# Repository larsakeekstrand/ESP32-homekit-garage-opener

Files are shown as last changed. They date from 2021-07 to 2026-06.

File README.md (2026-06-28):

# ESP32 Homekit garage door opener
## Introduction
This is a homekit garage opener for the ESP32. It's a bit a work in progress, but it should mostly work.

Features:
* Controls a relay that opens/closes the door.
* Uses a reed sensor to detect if the door is open/closed.
* Contains a DHT22 temperature/humidity sensor.

Schematics for the hardware can be found [here](https://github.com/larsakeekstrand/ESP32-homekit-garage-opener/blob/478886ba8ccb8f31c0db583b10b282738d822965/docs/Schematic_GarageOpener.pdf). The schematics is made using [EasyEDA](https://easyeda.com/)

STL files for the housing can be found [here](https://github.com/larsakeekstrand/ESP32-homekit-garage-opener/blob/2dc0cb2f88ffee0f719a3f48c10d991301077dc2/docs/GarageOpenerTop.stl), [here](https://github.com/larsakeekstrand/ESP32-homekit-garage-opener/blob/2dc0cb2f88ffee0f719a3f48c10d991301077dc2/docs/GarageOpenerBottom.stl) and [here](https://github.com/larsakeekstrand/ESP32-homekit-garage-opener/blob/d89407ebe4e6d4afd1c8a517a600cc80013ba3aa/docs/GarageOpenerBottomButton.stl).

An overview of how to assemble the housing can be found [here](https://github.com/larsakeekstrand/ESP32-homekit-garage-opener/blob/d89407ebe4e6d4afd1c8a517a600cc80013ba3aa/docs/GarageOpenerCompleteNotPrintable.stl).

## Getting started
### Setup host environment

Set up the host environment and **Espressif ESP-IDF v5.5.2** using the instructions given [here](https://docs.espressif.com/projects/esp-idf/en/latest/get-started/index.html).

Set up the Espressif esp-homekit-sdk using the instructions given [here](https://github.com/espressif/esp-homekit-sdk).

The DHT22/AM2301 driver is fetched automatically by the **ESP Component Manager** (declared in `main/idf_component.yml`) — no separate clone of `esp-idf-lib` is required.

### Get ESP32-homekit-garage-opener

Clone this repository **alongside** (not inside) your `~/esp/` directory:

```
cd ~/source    # ~/source is a sibling of ~/esp
git clone https://github.com/larsakeekstrand/ESP32-homekit-garage-opener
```

After the installation the directory structure should look like this:

```
~/
  esp/
    esp-idf            # ESP-IDF v5.5.2
    esp-homekit-sdk    # Espressif HomeKit SDK (cloned peer)
  source/
    ESP32-homekit-garage-opener   # this repo
```

`CMakeLists.txt` locates `esp-homekit-sdk` at `../../esp/esp-homekit-sdk` relative to the repo root, or via the `HOMEKIT_PATH` environment variable.

### Configure
Source the ESP-IDF environment, then run `idf.py menuconfig` to set Wi-Fi credentials and the HomeKit setup code before flashing:
```bash
. ~/esp/esp-idf/export.sh
cd ~/source/ESP32-homekit-garage-opener
idf.py menuconfig
```

Set the Wi-Fi SSID and password under **App Wi-Fi configuration**. Set the HomeKit setup code and ID under **HAP Setup** (or leave the hardcoded defaults for development).

### Compile and Flash

```bash
idf.py set-target esp32
idf.py build
idf.py flash monitor
```

## Continuous Integration & Releases



### CI (automatic)

Every push to `main` and every pull request targeting `main` triggers the **Build** workflow
(`.github/workflows/build.yml`). It:

- Builds the firmware with ESP-IDF v5.5.2 and target `esp32`.
- Verifies the image fits the 1600 KB OTA partition.
- Uploads `garage.bin` as a downloadable artifact.

Warnings in the app sources are treated as errors (`-Werror`), so a warning will fail the build.

### Cutting a release (manual)

1. Go to the **Actions** tab in GitHub.
2. Select the **Release** workflow.
3. Click **Run workflow**, enter a version string (e.g. `1.1.0`, no leading `v`), and confirm.

The workflow builds with that version baked in as `FW_VERSION`, tags the commit `v1.1.0`, and
publishes a GitHub Release with two assets: `garage.bin` and `version.txt`.

### Self-updating OTA

The device checks `releases/latest` on GitHub **every hour** (default). If `version.txt` reports a
version newer than the running firmware, the device downloads `garage.bin` via HTTPS and reboots
into the new image. A bad image that never completes initialization is **automatically rolled back**
by the bootloader.

The poll interval and repo base URL are configurable via `idf.py menuconfig` →
**Example Configuration** → OTA options (`CONFIG_OTA_POLL_INTERVAL_SEC`,
`CONFIG_OTA_GITHUB_BASE_URL`).

> **Security note:** anyone who can publish a GitHub Release to this repo can push firmware to the
> device. Images are not cryptographically signed — acceptable for a personal repo.

### Wi-Fi credentials & OTA

Wi-Fi credentials are stored in the **`nvs` flash partition**, which OTA never touches (OTA only
rewrites the inactive app slot). So **credentials persist across updates** — you don't re-enter them
when the device self-updates.

The release images built by CI are **provisioning-mode** (no credentials baked in). Don't put your
SSID/password into the build or into GitHub — provision the device instead:

- **First-time / after a reset:** when the device is unprovisioned it advertises a BLE service named
  `PROV_XXYYZZ` (last 3 bytes of its MAC) and prints a **QR code + proof-of-possession (POP)** to the
  serial monitor. Install Espressif's **ESP BLE Provisioning** app (iOS/Android), scan the QR code
  (or pick `PROV_XXYYZZ` and enter the POP), choose your Wi-Fi, and enter the password. The creds are
  saved to NVS over an encrypted BLE link.
- **Re-provision:** short-press the boot/reset button (~3 s) to reset the network → the device
  re-advertises for provisioning. A long press (~10 s) is a full factory reset (also unpairs
  HomeKit).

> A locally-built **hardcoded** image (`menuconfig` → App Wi-Fi → *Use hardcoded credentials*) is fine
> for bench testing, but the first OTA replaces it with a provisioning image. Because esp-wifi caches
> the hardcoded credentials in NVS, the provisioning image reconnects using them — but from then on
> the device is provisioning-based, so re-provision over BLE if you ever clear the network config.

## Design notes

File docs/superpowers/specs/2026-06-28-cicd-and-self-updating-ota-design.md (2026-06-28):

# CI/CD Pipeline + Self-Updating OTA — Design

**Date:** 2026-06-28
**Status:** Approved (pending spec review)
**Scope:** Add GitHub Actions CI (build on push/PR), a manually-triggered release workflow that
publishes an OTA image, and replace the HomeKit-triggered firmware upgrade with a self-polling
GitHub-release OTA updater.

## Goal

1. **CI:** every push to `main` and every PR to `main` builds the firmware on ESP-IDF v5.5.2 and
   fails on warnings or if the image won't fit the OTA partition.
2. **Release:** a manually-dispatched GitHub Actions workflow builds a versioned image and publishes
   it as a GitHub Release.
3. **OTA:** the device polls GitHub Releases on a schedule and auto-updates itself to the newest
   release, with rollback protection.

## Context & Constraints (from the existing codebase)

- ESP-IDF **v5.5.2**, target **esp32** only. Repo at `~/source/ESP32-homekit-garage-opener`
  (sibling of `~/esp/`); builds via `idf.py` after `. ~/esp/esp-idf/export.sh`.
- Dependencies: `esp-homekit-sdk` is a cloned git peer (no registry package), pinned commit
  **`676fabac4a4a05184be020611cb069faa0016411`**; the DHT driver is fetched by the Component
  Manager (`main/idf_component.yml`).
- Modules: `board.h`, `hap_garage.{c,h}`, `door_control.{c,h}`, `dht_sensor.{c,h}`, thin
  `app_main.c`.
- Partitions (`partitions_hap.csv`): dual OTA slots `ota_0`/`ota_1` at **1600K each**, plus
  `otadata`, `factory_nvs`, `nvs_keys`. The app image is currently **~98% of 1600K**.
- Current OTA: the HomeKit SDK `hap_fw_upgrade` service (hidden, custom UUID) with an empty
  `server_cert[]`. It is controller-triggered (a controller writes a URL characteristic) and the
  Apple Home app cannot drive it. This is being **replaced**.
- Repo GitHub slug: **`larsakeekstrand/ESP32-homekit-garage-opener`** (public).
- No automated test harness exists; the build is the verification gate.

## Key Decisions

- CI "test" = **build-only gate** (warnings-as-errors + partition-fit check). No unit tests.
- Release trigger = **manual `workflow_dispatch`** with a `version` input. Version is injected into
  the firmware and drives OTA comparison.
- OTA = **device self-polls hourly and auto-applies** newer releases (no HomeKit trigger, no
  manual step). Interval is menuconfig-configurable.
- The HomeKit `hap_fw_upgrade` service is **removed**.

## Design

### 1. CI build workflow — `.github/workflows/build.yml`

- **Triggers:** `push` to `main`; `pull_request` targeting `main`.
- **Job steps:**
  1. `actions/checkout`.
  2. Clone `esp-homekit-sdk` at the pinned commit `676fabac` into the runner and export
     `HOMEKIT_PATH` to it.
  3. Build with `espressif/esp-idf-ci-action@v1`, `esp_idf_version: v5.5.2`, target `esp32`,
     running `idf.py set-target esp32 build`. The Component Manager fetches the DHT driver
     (network available in CI).
  4. **Warnings-as-errors:** enabled for the project's own sources (via a build flag /
     `idf.py`-level setting), so new warnings fail CI. SDK/third-party warnings are not promoted.
  5. **Partition-fit gate:** read the produced app image size and fail the job if it exceeds the
     1600K `ota_0` slot. (Belt-and-suspenders: the linker already fails on overflow, but this gives
     a clear, early signal and guards the tight headroom.)
  6. Upload `build/garage.bin` as a CI artifact (inspection only; not a release).
- **No secrets required.**

### 2. Release workflow — `.github/workflows/release.yml`

- **Trigger:** `workflow_dispatch` with a required input `version` (e.g. `1.1.0`,
  no leading `v`).
- **Permissions:** `contents: write` (create tag + release).
- **Steps:**
  1. `actions/checkout`.
  2. Clone pinned `esp-homekit-sdk`; export `HOMEKIT_PATH`.
  3. Build via `esp-idf-ci-action` (v5.5.2, esp32) with the version injected:
     `idf.py -DFW_VERSION=<version> build` (see §3).
  4. Produce `version.txt` containing exactly `<version>`.
  5. Create git tag `v<version>` at the workflow's commit.
  6. Create a **GitHub Release** named `v<version>` with auto-generated notes, attaching **two
     assets**: `garage.bin` and `version.txt`.
- The release's assets are reachable at the stable URLs
  `https://github.com/larsakeekstrand/ESP32-homekit-garage-opener/releases/latest/download/garage.bin`
  and `.../releases/latest/download/version.txt`.

### 3. Build-time firmware version

- `CMakeLists.txt` (or `main/CMakeLists.txt`) reads a `FW_VERSION` CMake cache variable, defaulting
  to `0.0.0-dev` when unset (local/CI builds), and adds it as a compile definition
  (e.g. `-DFW_VERSION="0.0.0-dev"`).
- `hap_garage.c` uses `FW_VERSION` for `hap_acc_cfg_t.fw_rev` instead of the literal `"1.0.0"`.
- The OTA module (§4) uses the same `FW_VERSION` as its local-version baseline for comparison.

### 4. Self-updating OTA module — `main/ota_update.{c,h}`

- **Interface:**
  - `void ota_update_start(void);` — spawn the updater task.
  - `void ota_update_mark_valid(void);` — call after a healthy boot to confirm the running image
    and cancel pending rollback.
- **Task behavior** (low priority; loops):
  1. Sleep for the configured interval (Kconfig, default **3600 s**).
  2. HTTPS-GET `<base>/releases/latest/download/version.txt` into a small buffer, using an
     `esp_http_client`/`esp_https_ota` config with `crt_bundle_attach = esp_crt_bundle_attach`
     (trusts GitHub's CA chain via the IDF cert bundle; follows the `latest/download` redirect to
     the asset CDN).
  3. **Semver compare** the fetched version to `FW_VERSION` (parse `major.minor.patch`; ignore a
     `-dev` suffix → treat as oldest). If the remote is strictly newer, proceed; else loop.
  4. Run `esp_https_ota()` against `<base>/releases/latest/download/garage.bin` with the same cert
     bundle config. On success, log and `esp_restart()` into the new slot. On failure, log and
     continue the loop (retry next interval).
- `<base>` = `https://github.com/larsakeekstrand/ESP32-homekit-garage-opener` (defined via Kconfig
  so the owner/repo is configurable).
- **Rollback safety:**
  - Enable `CONFIG_BOOTLOADER_APP_ROLLBACK_ENABLE` (§6).
  - After boot reaches a healthy state (Wi-Fi connected + HomeKit started), `app_main`/the garage
    task calls `ota_update_mark_valid()` → `esp_ota_mark_app_valid_cancel_rollback()`. If a freshly
    OTA'd image never reaches that point (boot loop/crash), the bootloader reverts to the previous
    slot on the next reset.
- Spawned from `app_main` alongside the existing garage + DHT tasks.

### 5. Remove the HomeKit firmware-upgrade service

- In `hap_garage.c`: remove `#include <hap_fw_upgrade.h>`, the `server_cert[]` global, the
  `hap_fw_upgrade_config_t` + `hap_serv_fw_upgrade_create` call, and the corresponding
  `hap_acc_add_serv` for that service. The accessory keeps Garage Door Opener + Temperature +
  Humidity services only.

### 6. Configuration

- **`sdkconfig.defaults`:**
  - `CONFIG_MBEDTLS_CERTIFICATE_BUNDLE=y` — CA bundle for HTTPS to GitHub.
  - `CONFIG_BOOTLOADER_APP_ROLLBACK_ENABLE=y` — auto-revert bad OTA images.
  - `CONFIG_COMPILER_OPTIMIZATION_SIZE=y` — `-Os` for flash headroom (replaces the regenerated
    default `-Og`).
- **`main/Kconfig.projbuild`:** add
  - `OTA_POLL_INTERVAL_SEC` (int, default `3600`).
  - `OTA_GITHUB_BASE_URL` (string, default the repo's
    `https://github.com/larsakeekstrand/ESP32-homekit-garage-opener`).

### 7. Documentation

- Update `README.md` and `CLAUDE.md`: CI/release badges/notes, how to cut a release (dispatch the
  workflow with a version), and how the device self-updates (hourly poll of latest release;
  rollback behavior). Note the new `ota_update` module in the architecture list and that
  `hap_fw_upgrade` was removed.

## Verification

1. **Workflows:** lint the YAML and dry-run the equivalent build commands locally; confirm the
   build succeeds with `FW_VERSION` injected. (Cannot run GitHub Actions locally.)
2. **Build:** `idf.py build` clean with the new module + config; CI partition-fit gate passes.
3. **Release (user):** run the dispatch workflow once; confirm a `v<version>` Release with
   `garage.bin` + `version.txt`.
4. **OTA end-to-end (user, the real proof):** flash a build, publish a higher-versioned release,
   and confirm the device pulls + flashes + reboots into it within the poll interval, and that a
   deliberately-broken image rolls back.

## Out of Scope

- Unit tests / test harness.
- Signed OTA, secure boot, anti-rollback fuses (trust model: repo-release publishers can push code
  to the device — acceptable for a personal repo).
- Multi-target builds (esp32 only).
- Pushing updates to the device from CI (impossible across the LAN boundary; device-pull only).

## Risks

1. **`esp_https_ota` + GitHub `latest/download` redirect + cert bundle** — the make-or-break path.
   Mitigation: verify on-device early; if the redirect-to-CDN cert doesn't validate via the bundle,
   fall back to resolving the asset's direct URL or hosting elsewhere. The on-device OTA test is the
   proof.
2. **Partition headroom (~98%)** — adding the OTA module may overflow 1600K. Mitigation: `-Os`
   (expected to free ample space) + CI partition-fit gate. If still tight, revisit (e.g. resize OTA
   slots — larger change, would be flagged before doing it).
3. **Auto-update of a bad release** — mitigated by rollback (§4). The mark-valid placement must be
   correct (only after a genuinely healthy boot) or rollback won't protect.
4. **Unauthenticated `version.txt`/binary** — transport is authenticated (cert bundle) and only
   repo owners publish releases; no payload signature (documented, out of scope).

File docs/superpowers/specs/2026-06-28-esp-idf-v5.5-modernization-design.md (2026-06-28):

# ESP-IDF v5.5.2 Modernization & Cleanup — Design

**Date:** 2026-06-28
**Status:** Approved (pending spec review)
**Scope:** Migrate the HomeKit garage-door-opener firmware to ESP-IDF v5.5.2 and clean up
the existing code. No new features.

## Goal

Bring a multi-year-old ESP32 HomeKit garage-opener firmware up to date so it builds, flashes,
and runs on ESP-IDF **v5.5.2** (installed at `~/esp/esp-idf-v5.5.2`, symlinked `~/esp/esp-idf`),
and improve the quality of the existing single-file implementation — without changing the feature
set.

## Constraints & Decisions

- **Target chip:** ESP32 (classic, dual-core). Wiring unchanged from the current code.
- **Dependency strategy (Approach A):** ESP Component Manager for the DHT driver; re-clone
  `esp-homekit-sdk` as a git peer.
- **Code structure:** Split the single `app_main.c` (~760 lines) into focused modules.
- **No new features.** Behavior stays functionally identical except for two strict bug fixes
  (debounce, on-demand sensor read) called out below.
- **No automated tests** exist and the system is hardware-bound; verification is build-clean +
  on-device smoke test.

## Current State (baseline)

- Build: legacy GNU-make (`Makefile` + `main/component.mk`) **and** a converted
  `CMakeLists.txt`. The GNU-make path is dead in ESP-IDF v5.
- Dependencies, both currently **absent** from `~/esp/`:
  - `esp-homekit-sdk` — Espressif HomeKit SDK (provides `hap*`, `app_wifi`,
    `app_hap_setup_payload`, and a bundled `button`/`iot_button` component). Referenced via
    `EXTRA_COMPONENT_DIRS` with a `HOMEKIT_PATH` env override.
  - `esp-idf-lib` — UncleRus library, used only for the DHT (`dht.h`) driver.
- All logic in `main/app_main.c`: two FreeRTOS tasks (`garage_thread_entry`, `dht_thread_entry`)
  spawned from `app_main()`, sharing globals (`door_state`, `accessory`, `oneshot_timer`,
  `current_temperature`, `current_humidity`).
- Config: custom partition table `partitions_hap.csv` (dual OTA + factory_nvs),
  `sdkconfig.defaults` forces `CONFIG_FREERTOS_UNICORE=y`, 4 MB flash, watchdog off.

## Design

### 1. Build system & dependencies

- **Remove** `Makefile` and `main/component.mk` (legacy GNU-make; unsupported in v5).
- **Top-level `CMakeLists.txt`:** keep the `HOMEKIT_PATH` env override; set `EXTRA_COMPONENT_DIRS`
  to the re-cloned `esp-homekit-sdk` peer (`components/`, `components/homekit`, `examples/common`).
  Remove the `esp-idf-lib` peer path.
- **`main/idf_component.yml`** (new): declare the DHT driver as a managed dependency from the ESP
  Component Registry; the Component Manager fetches it into `managed_components/` on build. The
  exact registry package name is verified during implementation.
  - **Fallback (Approach B safety net):** if the registry package is unusable, vendor the two DHT
    driver files into a local `components/dht/`. This is a contingency, not the plan.
- **Re-clone `esp-homekit-sdk`** as `~/esp/esp-homekit-sdk`. **Its build compatibility with
  v5.5.2 is verified as the FIRST implementation step**, before any cleanup work, so SDK breakage
  surfaces immediately. Note: the SDK has no v5.5-tagged release — patching may be required.
- **Config:** keep `partitions_hap.csv` and `sdkconfig.defaults` (custom partition table,
  `FREERTOS_UNICORE`, 4 MB flash). Regenerate `sdkconfig` from defaults; remove `sdkconfig.old`.

### 2. Module decomposition

Split `main/app_main.c` into focused units under `main/`:

| File | Responsibility | State owned |
|---|---|---|
| `board.h` | All GPIO pin macros + board constants in one place | — |
| `door_control.{c,h}` | Door state machine: relay kick, reed-sensor debounce, state reconciliation, failsafe timer | `door_state`, `oneshot_timer` |
| `dht_sensor.{c,h}` | DHT polling task + cached latest temperature/humidity | `current_temperature`, `current_humidity` |
| `hap_garage.{c,h}` | HAP accessory creation, service/characteristic wiring, read/write callbacks, value-update helpers | `accessory` |
| `app_main.c` | Thin entry point: init board, build accessory, spawn the two tasks | — |

**Interface principles:**
- Modules communicate through small, explicit functions (e.g. `door_control_request_toggle()`,
  `dht_sensor_get(float *temp, float *hum)`).
- The HAP layer never touches GPIO directly; the door logic never references HAP UUIDs.
- `main/CMakeLists.txt` updated to register the new source files.

### 3. Behavior fixes during cleanup

1. **API migration:** `xQueueHandle` → `QueueHandle_t`; `portTICK_RATE_MS` →
   `portTICK_PERIOD_MS`; zero-initialize the `gpio_config_t` struct.
2. **Swapped DHT log** (`app_main.c:738`): the log prints the humidity value labeled "Temp" and
   vice-versa (args reversed relative to the format string). Fix.
3. **No-op `dht_read` callback** (`app_main.c:438`): currently empty, so on-demand HomeKit reads of
   temperature/humidity return stale defaults. Implement it to serve the cached values from
   `dht_sensor`.
4. **Unreliable debounce:** replace the bare edge-vs-last-value check (flagged by the author's own
   comment) with a short time-based debounce (~50 ms) for the reed sensor.
5. **De-duplicate the door state machine:** the `while(1)` loop has ~8 near-identical branches.
   Consolidate into an explicit `(sensor_edge, current_state) → (new_state, notifications)`
   transition so the logic is auditable.
6. **Remove dead code:** commented-out blocks and unused locals (e.g. `cur_val` in `dht_read`).

**Unchanged behavior:** same HomeKit services (Garage Door Opener, Temperature, Humidity, FW
Upgrade/OTA), same relay timing (300 ms kick, 8 s failsafe timer). The debounce and `dht_read` fixes
are the only observable behavior changes, and both are strict improvements.

### 4. Verification

1. **Build clean** on v5.5.2: `idf.py set-target esp32 && idf.py build` with zero errors; warnings
   triaged.
2. **On-device smoke test** (run by the user): `idf.py flash monitor` — pairs with HomeKit, reed
   sensor reflects door open/closed, relay actuates the door, temperature/humidity report.
3. **Docs:** update `README.md` and `CLAUDE.md` for the v5.5.2 workflow, the Component Manager
   dependency, and the new module layout.

Steps 1–2 require the SDK present and the device attached; the on-device smoke test depends on the
user, who will be given exactly what to watch.

## Out of Scope

- New features (MQTT/Home Assistant, additional sensors, status reporting, improved OTA).
- Multi-target support (S2/C3); ESP32 classic only.
- Security hardening (hardcoded setup code, disabled OTA cert verification) — noted but not
  addressed in this round.
- Automated test infrastructure.

## Risks

- **`esp-homekit-sdk` on v5.5.2** is the primary risk: no v5.5-tagged release. Mitigation: verify
  build as the first implementation step; patch the SDK or pin a compatible commit if needed.
- **DHT registry package** name/availability — mitigation: documented vendoring fallback.

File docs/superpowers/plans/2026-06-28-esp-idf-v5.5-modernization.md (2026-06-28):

# ESP-IDF v5.5.2 Modernization & Cleanup Implementation Plan

> **For agentic workers:** REQUIRED SUB-SKILL: Use superpowers:subagent-driven-development (recommended) or superpowers:executing-plans to implement this plan task-by-task. Steps use checkbox (`- [ ]`) syntax for tracking.

**Goal:** Migrate the ESP32 HomeKit garage-door-opener firmware to ESP-IDF v5.5.2 and split the single `app_main.c` into focused modules, fixing known bugs along the way — with no new features.

**Architecture:** Re-clone `esp-homekit-sdk` as a git peer; pull the DHT driver via the v5.5 Component Manager (`idf_component.yml`); CMake-only build. `app_main.c` becomes a thin composition root that orchestrates four focused modules: `board.h` (pins), `hap_garage` (all HomeKit I/O), `door_control` (door state machine + relay + reed sensor), and `dht_sensor` (temp/humidity task). `hap_garage` and `door_control` are mutually referencing C translation units (HomeKit write → door request; door state change → HomeKit notify) wired through their headers.

**Tech Stack:** C, ESP-IDF v5.5.2, FreeRTOS, Espressif HomeKit SDK (`hap*`, `app_wifi`), esp-idf-lib DHT driver, CMake + ESP Component Manager.

## Testing Note (read before starting)

This firmware has **no automated test harness** and is hardware-bound (CLAUDE.md: "no tests, linters, or CI"). Per the approved spec, verification is:
- **Per task:** a clean `idf.py build` (zero errors) is the objective gate. Where a task changes observable behavior, the step says exactly what to confirm.
- **Final (Task 7):** on-device smoke test run by the user via `idf.py flash monitor`.

Do **not** invent unit tests for this codebase — there is no framework and the logic is I/O-bound on GPIO/HAP. The build is the test cycle.

**Build command used throughout** (sources the toolchain, then builds):
```bash
. ~/esp/esp-idf/export.sh && idf.py build
```
First build in a fresh checkout also needs `idf.py set-target esp32` (Task 1).

## Global Constraints

- **ESP-IDF version:** v5.5.2 exactly (installed at `~/esp/esp-idf-v5.5.2`, symlinked `~/esp/esp-idf`).
- **Target chip:** `esp32` (classic) only. Do not add S2/C3 target support.
- **Workspace layout (verified):** repo lives at `~/source/ESP32-homekit-garage-opener`, a **sibling** of `~/esp/` (NOT nested inside it, despite what the old README/CLAUDE.md say). `esp-idf` is at `~/esp/esp-idf` (→ `esp-idf-v5.5.2`); `esp-homekit-sdk` is re-cloned at `~/esp/esp-homekit-sdk`. `CMakeLists.txt` honors the `HOMEKIT_PATH` env override, else falls back to `${CMAKE_CURRENT_LIST_DIR}/../../esp/esp-homekit-sdk` (which resolves to `~/esp/esp-homekit-sdk` from this checkout).
- **Pin map (unchanged):** reset/button GPIO0, running LED GPIO2, door LED GPIO16, relay GPIO5, reed sensor GPIO4, DHT22/AM2301 GPIO22.
- **Relay/timing (unchanged):** 300 ms relay kick, 8 s (`DOOR_MOVING_MAXTIME` = 8000000 µs) failsafe timer.
- **No new features.** Only the two behavior changes the spec authorizes: reed-sensor debounce, and a working on-demand `dht_read`.
- **Commit after every task.** Branch is `modernize-esp-idf-v5.5` (already created).
- **Logging:** keep `ESP_LOGI`/`ESP_LOGE` with the `"HAP Garage"` tag style.

---

### Task 1: Build-system migration + dependency wiring + mechanical API fixes → first clean build

Retire the biggest risk (does `esp-homekit-sdk` build on v5.5.2?) by getting the **existing, behavior-unchanged** code to compile on the new toolchain. Bundles all the changes required to reach the first green build; none of them is independently build-testable on its own.

**Files:**
- Delete: `Makefile`, `main/component.mk`, `sdkconfig.old`, `sdkconfig`
- Modify: `CMakeLists.txt`
- Create: `main/idf_component.yml`
- Modify: `main/app_main.c` (mechanical API fixes only)

**Interfaces:**
- Consumes: nothing (first task).
- Produces: a buildable v5.5.2 project. No new C symbols yet.

- [ ] **Step 1: Re-clone the HomeKit SDK peer**

```bash
cd ~/esp
git clone --recursive https://github.com/espressif/esp-homekit-sdk.git
cd ~/esp/esp-homekit-sdk && git log --oneline -1
```
Expected: `esp-homekit-sdk/` exists with submodules checked out (the `esp_hap_*` components and `examples/common`). Record the commit hash in the final commit message.

- [ ] **Step 2: Remove the legacy GNU-make build and stale config**

```bash
cd ~/source/ESP32-homekit-garage-opener
git rm Makefile main/component.mk sdkconfig.old
rm -f sdkconfig   # regenerated from sdkconfig.defaults on next build; not tracked-critical
```
Expected: files removed. `sdkconfig.defaults` and `partitions_hap.csv` remain.

- [ ] **Step 3: Rewrite the top-level `CMakeLists.txt`**

Replace the entire file with (drops the `esp-idf-lib` peer path; keeps `HOMEKIT_PATH` override):

```cmake
# ESP32 HomeKit garage door opener — ESP-IDF v5.5.2
cmake_minimum_required(VERSION 3.16)

if(DEFINED ENV{HOMEKIT_PATH})
  set(HOMEKIT_PATH $ENV{HOMEKIT_PATH})
else()
  # This repo lives at ~/source/ESP32-homekit-garage-opener, a sibling of ~/esp/,
  # so the SDK (cloned next to esp-idf) is at ../../esp/esp-homekit-sdk.
  set(HOMEKIT_PATH ${CMAKE_CURRENT_LIST_DIR}/../../esp/esp-homekit-sdk)
endif()

set(EXTRA_COMPONENT_DIRS
    ${HOMEKIT_PATH}/components
    ${HOMEKIT_PATH}/components/homekit
    ${HOMEKIT_PATH}/examples/common)

include($ENV{IDF_PATH}/tools/cmake/project.cmake)
project(garage)
```

- [ ] **Step 4: Add the DHT dependency manifest**

Create `main/idf_component.yml`:

```yaml
## Managed dependencies for the garage opener firmware.
dependencies:
  idf:
    version: ">=5.5.0"
  # DHT22 / AM2301 driver (UncleRus esp-idf-lib, ESP Component Registry).
  esp-idf-lib/dht: "^1.0.0"
```

- [ ] **Step 5: Verify the DHT package name/version resolves; correct if needed**

```bash
. ~/esp/esp-idf/export.sh
cd ~/source/ESP32-homekit-garage-opener
idf.py reconfigure 2>&1 | tee /tmp/dht_resolve.log
```
Expected: the Component Manager resolves and downloads a `dht` component into `managed_components/`.
- If resolution fails with "version not found" / "component not found", run `idf.py add-dependency "esp-idf-lib/dht"` and read the resolved name/version it writes into `main/idf_component.yml`; keep that.
- **Fallback (only if the registry has no usable `dht`):** vendor it instead — `mkdir -p components/dht`, copy `dht.c`, `dht.h`, and `CMakeLists.txt` from a checkout of `https://github.com/UncleRus/esp-idf-lib` (`components/dht/`) into `components/dht/`, and delete `main/idf_component.yml`. The `#include <dht.h>` in `app_main.c` resolves the same way either path.

- [ ] **Step 6: Apply mechanical API fixes in `main/app_main.c`**

These three are deprecated/removed in v5.5. Make exactly these edits:

1. Queue handle type (line ~76):
```c
// before: static xQueueHandle gpio_evt_queue = NULL;
static QueueHandle_t gpio_evt_queue = NULL;
```
2. Tick-period macro — both occurrences (`kick_door_relay` ~line 130, `dht_thread_entry` ~line 745):
```c
// before: vTaskDelay(300 / portTICK_RATE_MS);
vTaskDelay(300 / portTICK_PERIOD_MS);
// before: vTaskDelay(30000 / portTICK_RATE_MS);
vTaskDelay(30000 / portTICK_PERIOD_MS);
```
3. Zero-initialize the GPIO config struct in `setup_gpio` (~line 155) so the v5.x `gpio_config_t` (which gained fields) has no indeterminate members:
```c
// before: gpio_config_t io_conf;
gpio_config_t io_conf = {0};
```

- [ ] **Step 7: Set target and build clean**

```bash
. ~/esp/esp-idf/export.sh
cd ~/source/ESP32-homekit-garage-opener
idf.py set-target esp32
idf.py build 2>&1 | tail -30
```
Expected: `Project build complete.` with zero errors. Triage warnings: deprecation warnings from inside `esp-homekit-sdk` are acceptable to note; errors are not. If the SDK itself fails to compile on v5.5.2, **stop and report** — this is the spec's identified risk and may require pinning a different SDK commit or patching it (out of band of this plan).

- [ ] **Step 8: Commit**

```bash
git add -A
git commit -m "build: migrate to ESP-IDF v5.5.2 (CMake-only, Component Manager DHT)

Remove legacy GNU-make build; re-point EXTRA_COMPONENT_DIRS at re-cloned
esp-homekit-sdk peer; add idf_component.yml for the DHT driver. Mechanical
API fixes: xQueueHandle->QueueHandle_t, portTICK_RATE_MS->portTICK_PERIOD_MS,
zero-init gpio_config_t. Behavior unchanged. esp-homekit-sdk @ <hash>.

Co-Authored-By: Claude Opus 4.8 (1M context) <noreply@anthropic.com>"
```

---

### Task 2: Extract `board.h`

Pure mechanical extraction of all pin/board macros into one header. Lowest-risk first refactor step.

**Files:**
- Create: `main/board.h`
- Modify: `main/app_main.c`

**Interfaces:**
- Consumes: nothing.
- Produces: `board.h` defining `RESET_GPIO`, `RUNNING_LED_GPIO`, `DOOR_LED_GPIO`, `DOOR_RELAY_GPIO`, `DOOR_SENSOR_GPIO`, `DHT_SENSOR_GPIO`, `GPIO_OUTPUT_PIN_SEL`, `GPIO_INPUT_PIN_SEL`, `ESP_INTR_FLAG_DEFAULT`.

- [ ] **Step 1: Create `main/board.h`**

```c
//
// board.h — GPIO pin map and board-level constants.
//
#pragma once

#include <driver/gpio.h>

/* The "Boot" button doubles as Wi-Fi reset (short) / factory reset (long). */
#define RESET_GPIO        GPIO_NUM_0

#define RUNNING_LED_GPIO  GPIO_NUM_2
#define DOOR_LED_GPIO     GPIO_NUM_16
#define DOOR_RELAY_GPIO   GPIO_NUM_5
#define DOOR_SENSOR_GPIO  GPIO_NUM_4
#define DHT_SENSOR_GPIO   GPIO_NUM_22

#define GPIO_OUTPUT_PIN_SEL  ((1ULL<<RUNNING_LED_GPIO) | (1ULL<<DOOR_LED_GPIO) | (1ULL<<DOOR_RELAY_GPIO))
#define GPIO_INPUT_PIN_SEL   (1ULL<<DOOR_SENSOR_GPIO)

#define ESP_INTR_FLAG_DEFAULT 0
```

- [ ] **Step 2: Remove the moved macros from `app_main.c` and include the header**

In `main/app_main.c`, delete the macro definitions now living in `board.h` (the `RESET_GPIO`, `RUNNING_LED_GPIO`, `DOOR_LED_GPIO`, `DOOR_RELAY_GPIO`, `DOOR_SENSOR_GPIO`, `GPIO_OUTPUT_PIN_SEL`, `GPIO_INPUT_PIN_SEL`, `DHT_SENSOR_GPIO`, `ESP_INTR_FLAG_DEFAULT` lines, ~lines 46–58). Add near the top includes:
```c
#include "board.h"
```

- [ ] **Step 3: Build clean**

```bash
. ~/esp/esp-idf/export.sh && cd ~/source/ESP32-homekit-garage-opener && idf.py build 2>&1 | tail -15
```
Expected: `Project build complete.`, zero errors. (No `idf_component_register` change needed — headers in `main/` are found automatically.)

- [ ] **Step 4: Commit**

```bash
git add -A && git commit -m "refactor: extract board.h with GPIO pin map

Co-Authored-By: Claude Opus 4.8 (1M context) <noreply@anthropic.com>"
```

---

### Task 3: Extract `hap_garage.{c,h}` (all HomeKit I/O)

Move accessory creation, services, callbacks, HomeKit notify helpers, and the HAP/Wi-Fi lifecycle into one module. `hap_garage` is the **only** place that touches `hap_*` APIs. It calls into `door_control`/`dht_sensor` through their headers (declarations created here; definitions stay in `app_main.c` until Tasks 4–5, so it links).

**Files:**
- Create: `main/hap_garage.h`, `main/hap_garage.c`
- Create: `main/door_control.h` (declarations only this task)
- Create: `main/dht_sensor.h` (declarations only this task)
- Modify: `main/app_main.c`, `main/CMakeLists.txt`

**Interfaces:**
- Consumes (declared now, defined later): from `door_control.h` — `uint8_t door_get_state(void);`, `void door_handle_homekit_request(void);`; from `dht_sensor.h` — `void dht_sensor_get(float *temperature, float *humidity);`.
- Produces (in `hap_garage.h`):
  - `void hap_garage_init(void);` — builds accessory + services, registers callbacks, inits HAP + Wi-Fi, starts HAP. Does **not** block.
  - `void hap_garage_start_wifi(void);` — calls `app_wifi_start(portMAX_DELAY)` (blocking); called from the garage task.
  - `void hap_garage_send_current_door_state(uint8_t state);`
  - `void hap_garage_send_target_door_state(uint8_t state);`
  - `void hap_garage_send_current_temperature(float temperature);`
  - `void hap_garage_send_current_humidity(float humidity);`
  - door-state enum macros `HOMEKIT_CHARACTERISTIC_CURRENT_DOOR_STATE_*` and `HOMEKIT_CHARACTERISTIC_TARGET_DOOR_STATE_*` (moved here so both `hap_garage` and `door_control` share them).

- [ ] **Step 1: Create `main/hap_garage.h`**

```c
//
// hap_garage.h — HomeKit (HAP) accessory: services, callbacks, notifications.
//
#pragma once

#include <stdint.h>

/* Current door state (mirrors HAP spec enum). */
#define HOMEKIT_CHARACTERISTIC_CURRENT_DOOR_STATE_OPEN    0
#define HOMEKIT_CHARACTERISTIC_CURRENT_DOOR_STATE_CLOSED  1
#define HOMEKIT_CHARACTERISTIC_CURRENT_DOOR_STATE_OPENING 2
#define HOMEKIT_CHARACTERISTIC_CURRENT_DOOR_STATE_CLOSING 3
#define HOMEKIT_CHARACTERISTIC_CURRENT_DOOR_STATE_STOPPED 4
#define HOMEKIT_CHARACTERISTIC_CURRENT_DOOR_STATE_UNKNOWN 255

/* Target door state. */
#define HOMEKIT_CHARACTERISTIC_TARGET_DOOR_STATE_OPEN    0
#define HOMEKIT_CHARACTERISTIC_TARGET_DOOR_STATE_CLOSED  1
#define HOMEKIT_CHARACTERISTIC_TARGET_DOOR_STATE_UNKNOWN 255

/* Lifecycle. */
void hap_garage_init(void);
void hap_garage_start_wifi(void);

/* Push updates to HomeKit. */
void hap_garage_send_current_door_state(uint8_t state);
void hap_garage_send_target_door_state(uint8_t state);
void hap_garage_send_current_temperature(float temperature);
void hap_garage_send_current_humidity(float humidity);
```

- [ ] **Step 2: Create `main/door_control.h` (declarations only)**

```c
//
// door_control.h — door state machine, relay, reed sensor.
//
#pragma once

#include <stdint.h>

/* Door open/closed sensor logical values. */
#define DOOR_OPEN   1
#define DOOR_CLOSED 0

/* Failsafe: max time a move may take before we trust the sensor (µs). */
#define DOOR_MOVING_MAXTIME 8000000

/* Current logical door state (HOMEKIT_CHARACTERISTIC_CURRENT_DOOR_STATE_*). */
uint8_t door_get_state(void);

/* Handle an open/close request arriving from HomeKit (kicks relay, arms timer). */
void door_handle_homekit_request(void);

/* Initialize door GPIO + ISR + queue and publish the initial state. */
void door_control_init(void);

/* Run the reed-sensor event loop forever (call from the garage task). */
void door_control_run_loop(void);
```

- [ ] **Step 3: Create `main/dht_sensor.h` (declarations only)**

```c
//
// dht_sensor.h — DHT22/AM2301 temperature + humidity.
//
#pragma once

/* Spawn the polling task. */
void dht_sensor_start(void);

/* Copy the latest cached readings (thread-safe enough on single-core). */
void dht_sensor_get(float *temperature, float *humidity);
```

- [ ] **Step 4: Create `main/hap_garage.c`**

Move the following from `app_main.c` **verbatim except where noted**, into `hap_garage.c`: `server_cert[]`, the `TAG`, `garage_identify`, `garage_hap_event_handler`, `door_state_to_string`, the four `send_*` helpers (renamed to the `hap_garage_send_*` signatures that take their value as a parameter), `garage_read`, `garage_write`, `dht_read`, and the accessory-building + lifecycle code currently inside `garage_thread_entry` (from `hap_get_config` through `hap_start()` and `reset_key_init`). Also move `reset_network_handler`, `reset_to_factory_handler`, `reset_key_init`.

```c
//
// hap_garage.c — HomeKit accessory and all HAP I/O.
//
#include <string.h>
#include <esp_log.h>
#include <esp_event.h>

#include <hap.h>
#include <hap_apple_servs.h>
#include <hap_apple_chars.h>
#include <hap_fw_upgrade.h>
#include <iot_button.h>
#include <app_wifi.h>
#include <app_hap_setup_payload.h>

#include "hap_garage.h"
#include "door_control.h"
#include "dht_sensor.h"
#include "board.h"

static const char *TAG = "HAP Garage";

/* Required for OTA server verification, PEM as string (empty = disabled). */
char server_cert[] = {};

static hap_acc_t *accessory;

/* Reset button timeouts. */
#define RESET_NETWORK_BUTTON_TIMEOUT    3
#define RESET_TO_FACTORY_BUTTON_TIMEOUT 10

// ---- move verbatim from app_main.c: door_state_to_string ----
// ---- move from app_main.c, adapting to parameterized values: the four send_* ----
// Example of the adaptation (current door state):
void hap_garage_send_current_door_state(uint8_t state) {
  hap_val_t door_value = { .u = state };
  hap_serv_t *service = hap_acc_get_serv_by_uuid(accessory, HAP_SERV_UUID_GARAGE_DOOR_OPENER);
  hap_char_t *handle  = hap_serv_get_char_by_uuid(service, HAP_CHAR_UUID_CURRENT_DOOR_STATE);
  ESP_LOGI(TAG, "Sending current doorstate [%s]", door_state_to_string(state));
  hap_char_update_val(handle, &door_value);
}
// (send_target_door_state likewise; the two sensor helpers take a float param
//  and read nothing global — see Step 5 for their bodies.)

// ---- garage_identify, garage_hap_event_handler: move verbatim ----
// ---- reset_network_handler, reset_to_factory_handler, reset_key_init: move verbatim ----
```

For `garage_read` (move verbatim) the only change: it already calls `get_door_state()` — rename those calls to `door_get_state()`.

For `garage_write` (move, then gut): replace its body with a single delegation, because the open/close decision + relay + timer logic moves to `door_control` (Task 5):
```c
static int garage_write(hap_write_data_t write_data[], int count,
                        void *serv_priv, void *write_priv) {
  door_handle_homekit_request();
  return HAP_SUCCESS;
}
```

For `dht_read` (move, then implement — fixes spec bug #3): serve cached values instead of doing nothing:
```c
static int dht_read(hap_char_t *hc, hap_status_t *status_code,
                    void *serv_priv, void *read_priv) {
  float t = 0, h = 0;
  dht_sensor_get(&t, &h);
  hap_val_t v;
  const char *uuid = hap_char_get_type_uuid(hc);
  if (!strcmp(uuid, HAP_CHAR_UUID_CURRENT_TEMPERATURE)) { v.f = t; hap_char_update_val(hc, &v); }
  else if (!strcmp(uuid, HAP_CHAR_UUID_CURRENT_RELATIVE_HUMIDITY)) { v.f = h; hap_char_update_val(hc, &v); }
  if (status_code) *status_code = HAP_STATUS_SUCCESS;
  return HAP_SUCCESS;
}
```

- [ ] **Step 5: Add `hap_garage_init` / `hap_garage_start_wifi` and the sensor send helpers**

Compose `hap_garage_init` from the accessory-building block currently in `garage_thread_entry` (lines ~496–607: `hap_get_config`/`hap_init`, `hap_acc_cfg_t cfg`, `hap_acc_create`, product data, the three service creations + `hap_serv_set_*_cb` + `hap_acc_add_serv`, FW-upgrade service, `hap_add_accessory`, `reset_key_init`, the hardcoded setup-code block, `hap_enable_mfi_auth`, `app_wifi_init`, `esp_event_handler_register`, `hap_start`). Wrap it as:
```c
void hap_garage_init(void) {
  /* ... moved accessory-building + lifecycle code, ending at hap_start(); ... */
}
void hap_garage_start_wifi(void) {
  app_wifi_start(portMAX_DELAY);
}
```
And the two sensor notify helpers (parameterized, no globals):
```c
void hap_garage_send_current_temperature(float temperature) {
  hap_val_t v = { .f = temperature };
  hap_serv_t *s = hap_acc_get_serv_by_uuid(accessory, HAP_SERV_UUID_TEMPERATURE_SENSOR);
  hap_char_t *h = hap_serv_get_char_by_uuid(s, HAP_CHAR_UUID_CURRENT_TEMPERATURE);
  ESP_LOGI(TAG, "Sending current temperature [%f]", temperature);
  hap_char_update_val(h, &v);
}
void hap_garage_send_current_humidity(float humidity) {
  hap_val_t v = { .f = humidity };
  hap_serv_t *s = hap_acc_get_serv_by_uuid(accessory, HAP_SERV_UUID_HUMIDITY_SENSOR);
  hap_char_t *h = hap_serv_get_char_by_uuid(s, HAP_CHAR_UUID_CURRENT_RELATIVE_HUMIDITY);
  ESP_LOGI(TAG, "Sending current humidity [%f]", humidity);
  hap_char_update_val(h, &v);
}
```
Note: `hap_serv_set_write_cb(service, garage_write)` and the `hap_serv_set_read_cb(..., dht_read)` registrations stay inside `hap_garage_init`, pointing at the now-local static callbacks. The `app_hap_setup_payload` macro guard (`CONFIG_APP_WIFI_USE_WAC_PROVISIONING`) and `CONFIG_EXAMPLE_USE_HARDCODED_SETUP_CODE` block move verbatim.

- [ ] **Step 6: Temporarily keep `app_main.c` linking**

In `app_main.c`, delete everything moved in Steps 4–5. Leave (for now) the door/dht globals and functions: `door_state`, `current_temperature`, `current_humidity`, `oneshot_timer`, `gpio_evt_queue`, `read_door_sensor`, `get_door_state`, `set_door_state`, `kick_door_relay`, `timer_callback`, `setup_gpio`, `gpio_isr_handler`, `dht_thread_entry`, and the door event loop. Add shims so the new headers' symbols resolve to the still-here definitions:
```c
#include "hap_garage.h"
#include "door_control.h"
#include "dht_sensor.h"

/* Temporary shims — removed in Tasks 4–5 when these move to their modules. */
uint8_t door_get_state(void) { return get_door_state(); }
void dht_sensor_get(float *t, float *h) { *t = current_temperature; *h = current_humidity; }
```
Leave `door_handle_homekit_request`, `door_control_init`, `door_control_run_loop`, `dht_sensor_start` **undefined for now only if unreferenced**. They ARE referenced (by `hap_garage` and, after this task, by the garage task). To keep it linking this task, also add temporary shims:
```c
void door_handle_homekit_request(void) {
  /* same body garage_write had before — kick relay, set OPENING/CLOSING, arm timer */
}
```
Move the original `garage_write` decision body into this shim verbatim (it will relocate to `door_control` in Task 5). Keep `garage_thread_entry`'s **event-loop tail** and initial-state code where it is for now, but rename its function to `door_control_run_loop` and split the GPIO+initial-state prefix into `door_control_init` (both still in `app_main.c` this task). Provide `dht_sensor_start` as a wrapper that `xTaskCreate`s the existing `dht_thread_entry`.

- [ ] **Step 7: Update `app_main()` to the new composition + register the new source**

`app_main.c` bottom:
```c
static void garage_thread_entry(void *p) {
  door_control_init();        // gpio + initial state (still defined in app_main this task)
  hap_garage_start_wifi();    // blocking
  door_control_run_loop();    // never returns
}

void app_main(void) {
  hap_garage_init();
  dht_sensor_start();
  xTaskCreate(garage_thread_entry, "hap_garage", 4*1024, NULL, 1, NULL);
}
```
Wait — `hap_garage_init` calls `app_wifi_init` which needs NVS; the original ran it inside the task. Keep the original ordering safe: move `hap_garage_init()` to the **first line of `garage_thread_entry`** instead of `app_main`, so all HAP/Wi-Fi setup stays on the task context exactly as before:
```c
static void garage_thread_entry(void *p) {
  hap_garage_init();
  door_control_init();
  hap_garage_start_wifi();
  door_control_run_loop();
}
void app_main(void) {
  xTaskCreate(garage_thread_entry, "hap_garage", 4*1024, NULL, 1, NULL);
  dht_sensor_start();
}
```
Update `main/CMakeLists.txt`:
```cmake
idf_component_register(SRCS "app_main.c" "hap_garage.c"
                       INCLUDE_DIRS ".")
```

- [ ] **Step 8: Build clean**

```bash
. ~/esp/esp-idf/export.sh && cd ~/source/ESP32-homekit-garage-opener && idf.py build 2>&1 | tail -20
```
Expected: `Project build complete.`, zero errors. The accessory init now runs on the garage task exactly as before; behavior unchanged except `dht_read` now returns live cached values.

- [ ] **Step 9: Commit**

```bash
git add -A && git commit -m "refactor: extract hap_garage module (all HomeKit I/O)

Move accessory creation, services, callbacks, notify helpers, and HAP/Wi-Fi
lifecycle into hap_garage.{c,h}. Implement dht_read to serve cached values
(was a no-op). garage_write now delegates to door_handle_homekit_request.
Temporary shims in app_main.c keep door/dht symbols linking until Tasks 4-5.

Co-Authored-By: Claude Opus 4.8 (1M context) <noreply@anthropic.com>"
```

---

### Task 4: Extract `dht_sensor.{c,h}` (task + cache + fix swapped log)

Move the DHT polling task and cached readings into their module, and fix the swapped temp/humidity log (spec bug #2).

**Files:**
- Create: `main/dht_sensor.c`
- Modify: `main/app_main.c`, `main/CMakeLists.txt`

**Interfaces:**
- Consumes: `hap_garage_send_current_temperature(float)`, `hap_garage_send_current_humidity(float)`.
- Produces: defines `dht_sensor_start(void)` and `dht_sensor_get(float*, float*)` declared in `dht_sensor.h` (Task 3). Removes the temporary `dht_sensor_get` shim from `app_main.c`.

- [ ] **Step 1: Create `main/dht_sensor.c`**

```c
//
// dht_sensor.c — DHT22/AM2301 polling task and cached readings.
//
#include <freertos/FreeRTOS.h>
#include <freertos/task.h>
#include <esp_log.h>
#include <dht.h>

#include "dht_sensor.h"
#include "hap_garage.h"
#include "board.h"

static const char *TAG = "HAP Garage";
static const dht_sensor_type_t sensor_type = DHT_TYPE_AM2301;

static float current_temperature = 0.0f;
static float current_humidity = 0.0f;

void dht_sensor_get(float *temperature, float *humidity) {
  *temperature = current_temperature;
  *humidity = current_humidity;
}

static void dht_thread_entry(void *p) {
  while (1) {
    if (dht_read_float_data(sensor_type, DHT_SENSOR_GPIO, &current_humidity, &current_temperature) == ESP_OK)
      ESP_LOGI(TAG, "Read Temp: %0.01fC Humidity: %0.01f%%", current_temperature, current_humidity);  // fixed arg order
    else
      ESP_LOGE(TAG, "Could not read data from DHT sensor on GPIO %d", DHT_SENSOR_GPIO);

    hap_garage_send_current_temperature(current_temperature);
    hap_garage_send_current_humidity(current_humidity);
    vTaskDelay(30000 / portTICK_PERIOD_MS);
  }
  vTaskDelete(NULL);
}

void dht_sensor_start(void) {
  xTaskCreate(dht_thread_entry, "hap_dht", 4*1024, NULL, 1, NULL);
}
```
Note the fix: `dht_read_float_data(..., &current_humidity, &current_temperature)` keeps the driver's `(humidity, temperature)` parameter order (correct), but the **log now prints temperature then humidity** matching its labels (the old code passed them swapped).

- [ ] **Step 2: Remove the moved code + shims from `app_main.c`**

Delete from `app_main.c`: `sensor_type`, `current_temperature`, `current_humidity`, `dht_thread_entry`, the temporary `dht_sensor_get` shim, the temporary `dht_sensor_start` wrapper, and the old `send_current_temperature`/`send_current_humidity` if any remnant remains. Remove the now-unused `#include <dht.h>`.

- [ ] **Step 3: Register the source**

```cmake
idf_component_register(SRCS "app_main.c" "hap_garage.c" "dht_sensor.c"
                       INCLUDE_DIRS ".")
```

- [ ] **Step 4: Build clean**

```bash
. ~/esp/esp-idf/export.sh && cd ~/source/ESP32-homekit-garage-opener && idf.py build 2>&1 | tail -15
```
Expected: `Project build complete.`, zero errors.

- [ ] **Step 5: Commit**

```bash
git add -A && git commit -m "refactor: extract dht_sensor module; fix swapped temp/humidity log

Co-Authored-By: Claude Opus 4.8 (1M context) <noreply@anthropic.com>"
```

---

### Task 5: Extract `door_control.{c,h}` + debounce + consolidate state machine

Move the door state machine, relay, reed-sensor ISR/queue, failsafe timer, and event loop into their module. Add a ~50 ms reed-sensor debounce (spec bug #4) and collapse the 8-branch loop into one explicit transition (spec bug #5).

**Files:**
- Create: `main/door_control.c`
- Modify: `main/app_main.c`, `main/CMakeLists.txt`

**Interfaces:**
- Consumes: `hap_garage_send_current_door_state(uint8_t)`, `hap_garage_send_target_door_state(uint8_t)`, and the `HOMEKIT_CHARACTERISTIC_*` macros from `hap_garage.h`.
- Produces: defines `door_get_state`, `door_handle_homekit_request`, `door_control_init`, `door_control_run_loop` (declared in `door_control.h`, Task 3). Removes the matching temporary shims/defs from `app_main.c`.

- [ ] **Step 1: Create `main/door_control.c` with state, relay, sensor, timer**

```c
//
// door_control.c — door state machine, relay, reed sensor, failsafe timer.
//
#include <freertos/FreeRTOS.h>
#include <freertos/task.h>
#include <freertos/queue.h>
#include <driver/gpio.h>
#include <esp_log.h>
#include <esp_timer.h>

#include "door_control.h"
#include "hap_garage.h"
#include "board.h"

static const char *TAG = "HAP Garage";

static QueueHandle_t gpio_evt_queue = NULL;
static uint8_t door_state = HOMEKIT_CHARACTERISTIC_CURRENT_DOOR_STATE_UNKNOWN;
static esp_timer_handle_t oneshot_timer;

uint8_t door_get_state(void) { return door_state; }
static void door_set_state(uint8_t s) { door_state = s; }

/* Reed switch: hardware reads inverted, so XOR to logical DOOR_OPEN/DOOR_CLOSED. */
static uint8_t read_door_sensor(void) { return gpio_get_level(DOOR_SENSOR_GPIO) ^ 1; }

static void kick_door_relay(void) {
  gpio_set_level(DOOR_RELAY_GPIO, 1);
  vTaskDelay(300 / portTICK_PERIOD_MS);
  gpio_set_level(DOOR_RELAY_GPIO, 0);
}

static void timer_callback(void *args) {
  ESP_LOGI(TAG, "Timer expired. Setting state according to sensor.");
  if (read_door_sensor() == DOOR_OPEN) {
    hap_garage_send_target_door_state(HOMEKIT_CHARACTERISTIC_TARGET_DOOR_STATE_OPEN);
    hap_garage_send_current_door_state(HOMEKIT_CHARACTERISTIC_CURRENT_DOOR_STATE_OPEN);
    door_set_state(HOMEKIT_CHARACTERISTIC_CURRENT_DOOR_STATE_OPEN);
  } else {
    hap_garage_send_target_door_state(HOMEKIT_CHARACTERISTIC_TARGET_DOOR_STATE_CLOSED);
    hap_garage_send_current_door_state(HOMEKIT_CHARACTERISTIC_CURRENT_DOOR_STATE_CLOSED);
    door_set_state(HOMEKIT_CHARACTERISTIC_CURRENT_DOOR_STATE_CLOSED);
  }
}

static const esp_timer_create_args_t oneshot_timer_args = {
  .callback = &timer_callback, .name = "one-shot"
};

static void IRAM_ATTR gpio_isr_handler(void *arg) {
  uint32_t gpio_num = (uint32_t) arg;
  xQueueSendFromISR(gpio_evt_queue, &gpio_num, NULL);
}
```

- [ ] **Step 2: Add `door_handle_homekit_request` (moved from the Task-3 shim)**

```c
void door_handle_homekit_request(void) {
  if (read_door_sensor() == DOOR_OPEN ||
      door_state == HOMEKIT_CHARACTERISTIC_CURRENT_DOOR_STATE_OPENING) {
    kick_door_relay();
    door_set_state(HOMEKIT_CHARACTERISTIC_CURRENT_DOOR_STATE_CLOSING);
    ESP_LOGI(TAG, "Received request to close door. Closing.");
  } else {
    kick_door_relay();
    door_set_state(HOMEKIT_CHARACTERISTIC_CURRENT_DOOR_STATE_OPENING);
    ESP_LOGI(TAG, "Received request to open door. Opening.");
  }
  esp_timer_start_once(oneshot_timer, DOOR_MOVING_MAXTIME);
}
```

- [ ] **Step 3: Add `door_control_init` (GPIO + ISR + queue + timer + initial state)**

Compose from the old `setup_gpio` plus the initial-state block from `garage_thread_entry`:
```c
void door_control_init(void) {
  gpio_config_t io_conf = {0};
  io_conf.intr_type = GPIO_INTR_DISABLE;
  io_conf.mode = GPIO_MODE_OUTPUT;
  io_conf.pin_bit_mask = GPIO_OUTPUT_PIN_SEL;
  gpio_config(&io_conf);

  gpio_set_level(RUNNING_LED_GPIO, 1);
  gpio_set_level(DOOR_LED_GPIO, 0);
  gpio_set_level(DOOR_RELAY_GPIO, 0);

  io_conf.intr_type = GPIO_INTR_ANYEDGE;
  io_conf.pin_bit_mask = GPIO_INPUT_PIN_SEL;
  io_conf.mode = GPIO_MODE_INPUT;
  io_conf.pull_up_en = 1;
  gpio_config(&io_conf);

  gpio_install_isr_service(ESP_INTR_FLAG_DEFAULT);
  gpio_isr_handler_add(DOOR_SENSOR_GPIO, gpio_isr_handler, (void *) DOOR_SENSOR_GPIO);
  gpio_evt_queue = xQueueCreate(10, sizeof(uint32_t));

  esp_timer_create(&oneshot_timer_args, &oneshot_timer);

  uint8_t sensor = read_door_sensor();
  ESP_LOGI(TAG, "Initial door state is: (%s)", sensor == DOOR_OPEN ? "open" : "closed");
  if (sensor == DOOR_OPEN) {
    door_set_state(HOMEKIT_CHARACTERISTIC_CURRENT_DOOR_STATE_OPEN);
    hap_garage_send_current_door_state(HOMEKIT_CHARACTERISTIC_CURRENT_DOOR_STATE_OPEN);
    hap_garage_send_target_door_state(HOMEKIT_CHARACTERISTIC_TARGET_DOOR_STATE_OPEN);
    gpio_set_level(DOOR_LED_GPIO, 1);
  } else {
    door_set_state(HOMEKIT_CHARACTERISTIC_CURRENT_DOOR_STATE_CLOSED);
    hap_garage_send_current_door_state(HOMEKIT_CHARACTERISTIC_CURRENT_DOOR_STATE_CLOSED);
    hap_garage_send_target_door_state(HOMEKIT_CHARACTERISTIC_TARGET_DOOR_STATE_CLOSED);
  }
}
```

- [ ] **Step 4: Add the consolidated, debounced event loop**

This replaces the original ~80-line, 8-branch loop. The reconciliation rule is: on a *debounced* sensor change, drive HomeKit to match the sensor, and clear any transient OPENING/CLOSING once the sensor settles. Behavior matches the original outcomes (manual or HomeKit-initiated both converge to the sensor truth) but in one readable block.

```c
/* Ignore reed edges that arrive within this window of the last accepted edge. */
#define DOOR_DEBOUNCE_US 50000

void door_control_run_loop(void) {
  uint32_t io_num;
  uint8_t last_sensor = read_door_sensor();
  int64_t last_change_us = 0;

  while (1) {
    if (xQueueReceive(gpio_evt_queue, &io_num, portMAX_DELAY) == pdFALSE) {
      ESP_LOGI(TAG, "Door trigger FAIL");
      continue;
    }

    int64_t now = esp_timer_get_time();
    if (now - last_change_us < DOOR_DEBOUNCE_US) {
      continue;  // debounce: too soon after the last accepted edge
    }

    uint8_t sensor = read_door_sensor();
    if (sensor == last_sensor) {
      continue;  // spurious edge, no real change
    }
    last_sensor = sensor;
    last_change_us = now;

    ESP_LOGI(TAG, "Door sensor %s (state was %s)",
             sensor == DOOR_OPEN ? "open" : "closed",
             door_get_state() == HOMEKIT_CHARACTERISTIC_CURRENT_DOOR_STATE_OPEN ? "open" : "not-open");

    if (sensor == DOOR_OPEN) {
      gpio_set_level(DOOR_LED_GPIO, 1);
      hap_garage_send_target_door_state(HOMEKIT_CHARACTERISTIC_TARGET_DOOR_STATE_OPEN);
      hap_garage_send_current_door_state(HOMEKIT_CHARACTERISTIC_CURRENT_DOOR_STATE_OPEN);
      door_set_state(HOMEKIT_CHARACTERISTIC_CURRENT_DOOR_STATE_OPEN);
    } else {
      gpio_set_level(DOOR_LED_GPIO, 0);
      hap_garage_send_target_door_state(HOMEKIT_CHARACTERISTIC_TARGET_DOOR_STATE_CLOSED);
      hap_garage_send_current_door_state(HOMEKIT_CHARACTERISTIC_CURRENT_DOOR_STATE_CLOSED);
      door_set_state(HOMEKIT_CHARACTERISTIC_CURRENT_DOOR_STATE_CLOSED);
    }
  }
}
```

- [ ] **Step 5: Remove all moved code + shims from `app_main.c`**

Delete from `app_main.c`: `door_state`, `gpio_evt_queue`, `oneshot_timer`, `oneshot_timer_args`, `timer_callback`, `kick_door_relay`, `gpio_isr_handler`, `setup_gpio`, `read_door_sensor`, `get_door_state`/`set_door_state`, the `door_get_state` shim, the `door_handle_homekit_request` shim, and the old `door_control_init`/`door_control_run_loop` bodies and the `DOOR_OPEN`/`DOOR_CLOSED`/`DOOR_MOVING_MAXTIME` and `HOMEKIT_CHARACTERISTIC_*` macros (now in headers). `app_main.c` should now contain only includes + `garage_thread_entry` + `app_main`.

- [ ] **Step 6: Register the source + build clean**

```cmake
idf_component_register(SRCS "app_main.c" "hap_garage.c" "dht_sensor.c" "door_control.c"
                       INCLUDE_DIRS ".")
```
```bash
. ~/esp/esp-idf/export.sh && cd ~/source/ESP32-homekit-garage-opener && idf.py build 2>&1 | tail -15
```
Expected: `Project build complete.`, zero errors.

- [ ] **Step 7: Commit**

```bash
git add -A && git commit -m "refactor: extract door_control; add reed debounce; consolidate state machine

Move door state machine, relay, ISR/queue, failsafe timer, and event loop
into door_control.{c,h}. Add ~50ms reed-sensor debounce and collapse the
8-branch reconciliation into one explicit transition.

Co-Authored-By: Claude Opus 4.8 (1M context) <noreply@anthropic.com>"
```

---

### Task 6: Finalize `app_main.c`, remove dead code, sanity-scan

`app_main.c` should already be thin; verify it, strip any leftover dead code/comments, and confirm a from-scratch clean build.

**Files:**
- Modify: `main/app_main.c`

**Interfaces:**
- Consumes: `hap_garage_init`, `hap_garage_start_wifi`, `door_control_init`, `door_control_run_loop`, `dht_sensor_start`.
- Produces: nothing new.

- [ ] **Step 1: Reduce `app_main.c` to the composition root**

The whole file should read approximately:
```c
//
// app_main.c — composition root: wires modules and starts the tasks.
//
#include <freertos/FreeRTOS.h>
#include <freertos/task.h>

#include "hap_garage.h"
#include "door_control.h"
#include "dht_sensor.h"

#define GARAGE_TASK_STACKSIZE (4 * 1024)

/* Garage task: HAP + Wi-Fi lifecycle, then the reed-sensor event loop. */
static void garage_thread_entry(void *p) {
  hap_garage_init();
  door_control_init();
  hap_garage_start_wifi();   // blocking
  door_control_run_loop();   // never returns
}

void app_main(void) {
  xTaskCreate(garage_thread_entry, "hap_garage", GARAGE_TASK_STACKSIZE, NULL, 1, NULL);
  dht_sensor_start();
}
```
Remove any remaining commented-out code, unused includes, and the `cur_val`-style leftovers (spec bug #6) anywhere they survived in the modules.

- [ ] **Step 2: Full clean rebuild**

```bash
. ~/esp/esp-idf/export.sh && cd ~/source/ESP32-homekit-garage-opener
idf.py fullclean && idf.py build 2>&1 | tail -20
```
Expected: `Project build complete.`, zero errors, from a clean tree.

- [ ] **Step 3: Grep for dead-code remnants**

```bash
grep -rn "xQueueHandle\|portTICK_RATE_MS\|//.*hap_char_update_val\|cur_val" main/
```
Expected: no matches (all deprecated APIs gone, no commented-out HAP calls, no stray `cur_val`).

- [ ] **Step 4: Commit**

```bash
git add -A && git commit -m "refactor: thin app_main.c to composition root; remove dead code

Co-Authored-By: Claude Opus 4.8 (1M context) <noreply@anthropic.com>"
```

---

### Task 7: Update docs + on-device smoke test

Bring `README.md` and `CLAUDE.md` in line with the v5.5.2 workflow, Component Manager dependency, and module layout; then verify on hardware.

**Files:**
- Modify: `README.md`, `CLAUDE.md`

**Interfaces:** none (docs + manual test).

- [ ] **Step 1: Update `README.md`**

Edit the "Getting started" and "Compile and Flash" sections: replace `make menuconfig` with `idf.py menuconfig`; update the workspace layout to drop `esp-idf-lib` (now a managed dependency); state ESP-IDF **v5.5.2** and target **esp32**; note `esp-homekit-sdk` is still a cloned peer. Remove references to the GNU-make build.

- [ ] **Step 2: Update `CLAUDE.md`**

Update the "Build environment", "Commands", and "Architecture" sections: dependencies are now (a) `esp-homekit-sdk` peer and (b) the DHT driver via `main/idf_component.yml` (Component Manager) — `esp-idf-lib` is no longer a peer; the legacy Makefile build is gone (CMake only); and the single-file architecture is now `board.h` + `hap_garage` + `door_control` + `dht_sensor` + thin `app_main.c`. Update the file-layout/architecture prose and note the new debounce and working on-demand `dht_read`.

- [ ] **Step 3: Commit docs**

```bash
git add README.md CLAUDE.md
git commit -m "docs: update README and CLAUDE.md for v5.5.2 + module layout

Co-Authored-By: Claude Opus 4.8 (1M context) <noreply@anthropic.com>"
```

- [ ] **Step 4: On-device smoke test (user runs)**

```bash
. ~/esp/esp-idf/export.sh && cd ~/source/ESP32-homekit-garage-opener
idf.py flash monitor
```
Confirm in the monitor log and the Home app:
1. Boots, logs `Initial door state is: (...)`, connects Wi-Fi, pairs/shows in HomeKit.
2. Toggling the door from HomeKit pulses the relay; the door moves; state converges (no stuck OPENING/CLOSING after the 8 s failsafe at most).
3. Manually opening/closing the door updates HomeKit within the debounce window (no flapping from contact bounce).
4. Temperature + humidity show real values and update (and an on-demand read in Home app returns current, not default, values).

- [ ] **Step 5: Finish the branch**

After the smoke test passes, use the `superpowers:finishing-a-development-branch` skill to choose merge/PR.

---

## Self-Review

**Spec coverage:**
- Build system migration (delete make, CMake-only) → Task 1. ✓
- Component Manager DHT + re-clone SDK + verify SDK first → Task 1 (Steps 1, 4, 5, 7). ✓
- Module split (board/door_control/dht_sensor/hap_garage/thin app_main) → Tasks 2–6. ✓
- API migration (xQueueHandle, portTICK_RATE_MS, gpio_config_t) → Task 1 Step 6. ✓
- Swapped DHT log fix → Task 4 Step 1. ✓
- No-op dht_read fix → Task 3 Step 4. ✓
- Reed debounce → Task 5 Step 4. ✓
- De-duplicate state machine → Task 5 Step 4. ✓
- Remove dead code → Task 6. ✓
- Keep partition table / sdkconfig.defaults / FREERTOS_UNICORE → Task 1 Step 2 (left intact). ✓
- Verification build-clean + on-device → every task + Task 7. ✓
- Docs update → Task 7. ✓
- Out of scope (features, multi-target, security) → not present in any task. ✓

**Placeholder scan:** No "TBD/TODO/implement later". The only "verify and correct" step (Task 1 Step 5, DHT package name) is a genuine resolution action with a concrete command and a fully-specified vendoring fallback — not a placeholder.

**Type consistency:** `door_get_state` (uint8_t), `door_handle_homekit_request(void)`, `dht_sensor_get(float*, float*)`, `hap_garage_send_*` (uint8_t for door, float for sensors) are used identically in their consuming tasks (3, 4, 5). The `HOMEKIT_CHARACTERISTIC_*` macros live in `hap_garage.h` and are consumed by `door_control.c`. Consistent.

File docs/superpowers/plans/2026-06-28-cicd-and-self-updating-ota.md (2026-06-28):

# CI/CD + Self-Updating OTA Implementation Plan

> **For agentic workers:** REQUIRED SUB-SKILL: Use superpowers:subagent-driven-development (recommended) or superpowers:executing-plans to implement this plan task-by-task. Steps use checkbox (`- [ ]`) syntax for tracking.

**Goal:** Add GitHub Actions CI (build on push/PR), a manually-dispatched release workflow that publishes an OTA image, and a self-polling GitHub-release OTA updater on the device that replaces the HomeKit firmware-upgrade trigger.

**Architecture:** Firmware version is injected at build time (`FW_VERSION` → `fw_rev` and the OTA baseline). A new `ota_update` module runs a low-priority task that hourly fetches `version.txt` from the repo's latest GitHub Release, semver-compares it to the running version, and `esp_https_ota()`s from the release's `garage.bin` (trusting GitHub via the IDF cert bundle), with bootloader rollback protecting against bad images. CI builds on push/PR; a `workflow_dispatch` release workflow tags + publishes `garage.bin` + `version.txt`.

**Tech Stack:** C, ESP-IDF v5.5.2, FreeRTOS, `esp_https_ota`/`esp_http_client`/`app_update`/`esp_crt_bundle`, Espressif HomeKit SDK, GitHub Actions (`espressif/esp-idf-ci-action`), CMake + ESP Component Manager.

## Testing Note (read before starting)

This firmware has **no automated test harness** (CLAUDE.md: "no tests, linters, or CI" — this plan adds CI, not unit tests). Per the approved spec, verification is build-clean + on-device. So:
- **Per task:** a clean `idf.py build` (zero errors) is the gate. `main/CMakeLists.txt` compiles our own component with `-Werror` (added in Task 1), so any warning in our code fails the build — this is also what makes CI a real gate.
- **One exception:** the semver comparison (Task 3) is pure logic; that task includes a throwaway host-`cc` check of just that function (run, confirm, discard — not committed, no harness added).
- **GitHub Actions** (Tasks 5–6) cannot be run locally; verify by YAML-validating and dry-running the underlying build commands. The first push/dispatch is the real proof (the user will do that).

**Build command throughout:**
```bash
. ~/esp/esp-idf/export.sh && cd ~/source/ESP32-homekit-garage-opener && idf.py build
```
Note `sdkconfig` is gitignored (regenerated from `sdkconfig.defaults`); after editing `sdkconfig.defaults` run `idf.py reconfigure` (or just `idf.py build`).

## Global Constraints

- **ESP-IDF v5.5.2**, target **esp32** only.
- **Repo slug:** `larsakeekstrand/ESP32-homekit-garage-opener`; OTA base URL `https://github.com/larsakeekstrand/ESP32-homekit-garage-opener`.
- **esp-homekit-sdk** pinned commit `676fabac4a4a05184be020611cb069faa0016411` (CI clones it; locally it's the `~/esp/esp-homekit-sdk` peer).
- **OTA partition:** 1600K (1638400 bytes) per slot; the app must fit. App was ~98% full before this work — `-Os` (Task 2) creates headroom.
- **Release asset names:** `garage.bin` (the app image, ESP-IDF names it after `project(garage)`) and `version.txt`.
- **Default poll interval:** 3600 s (hourly), menuconfig-configurable.
- **Default `FW_VERSION`:** `0.0.0-dev` (local/CI builds); releases pass the real version.
- **Logging tag:** keep the `"HAP Garage"` style; OTA module may use its own tag `"OTA"`.
- **No new features beyond the spec.** Remove `hap_fw_upgrade`.
- **Commit after every task.** Branch `cicd-self-updating-ota` (already created). Stage files explicitly (the tree is otherwise clean).

---

### Task 1: Build-time `FW_VERSION` injection + `-Werror` for our component

Wire a compile-time version string into the firmware and lock in warning-free builds.

**Files:**
- Modify: `main/CMakeLists.txt`
- Modify: `main/hap_garage.c` (the `.fw_rev` line)

**Interfaces:**
- Consumes: nothing.
- Produces: a preprocessor macro `FW_VERSION` (a string literal, e.g. `"0.0.0-dev"`) available to all `main/` sources, overridable via `idf.py -DFW_VERSION=<v> build`.

- [ ] **Step 1: Update `main/CMakeLists.txt`**

Replace its contents with:
```cmake
idf_component_register(SRCS "app_main.c" "hap_garage.c" "dht_sensor.c" "door_control.c"
                       INCLUDE_DIRS ".")

# Firmware version: overridable with `idf.py -DFW_VERSION=1.2.3 build`.
if(NOT DEFINED FW_VERSION OR FW_VERSION STREQUAL "")
  set(FW_VERSION "0.0.0-dev")
endif()
message(STATUS "Building firmware version: ${FW_VERSION}")
target_compile_definitions(${COMPONENT_LIB} PRIVATE FW_VERSION="${FW_VERSION}")

# Treat warnings in our own code as errors (does not affect the SDK/third-party components).
target_compile_options(${COMPONENT_LIB} PRIVATE -Werror)
```
(Note: `ota_update.c` is added to SRCS in Task 3.)

- [ ] **Step 2: Use `FW_VERSION` for `fw_rev` in `main/hap_garage.c`**

Find `.fw_rev = "1.0.0",` (around line 272) and change it to:
```c
        .fw_rev = FW_VERSION,
```

- [ ] **Step 3: Build clean (default version)**

```bash
. ~/esp/esp-idf/export.sh && cd ~/source/ESP32-homekit-garage-opener && idf.py build 2>&1 | tail -15
```
Expected: `Project build complete.`, zero errors, and a `Building firmware version: 0.0.0-dev` line earlier in the configure output.

- [ ] **Step 4: Verify the override path works**

```bash
idf.py -DFW_VERSION=9.9.9 reconfigure 2>&1 | grep "Building firmware version"
```
Expected: `Building firmware version: 9.9.9`. Then reset back: `idf.py -DFW_VERSION=0.0.0-dev reconfigure >/dev/null`.

- [ ] **Step 5: Commit**

```bash
git add main/CMakeLists.txt main/hap_garage.c
git commit -m "feat: inject FW_VERSION at build time; -Werror for app sources

Co-Authored-By: Claude Opus 4.8 (1M context) <noreply@anthropic.com>"
```

---

### Task 2: Config — cert bundle, OTA rollback, size optimization, Kconfig options

Enable the platform features the OTA module needs and add its tunables.

**Files:**
- Modify: `sdkconfig.defaults`
- Modify: `main/Kconfig.projbuild`

**Interfaces:**
- Consumes: nothing.
- Produces: Kconfig symbols `CONFIG_OTA_POLL_INTERVAL_SEC` (int) and `CONFIG_OTA_GITHUB_BASE_URL` (string), plus the cert-bundle / rollback / `-Os` build settings.

- [ ] **Step 1: Append OTA/build settings to `sdkconfig.defaults`**

Add these lines to `sdkconfig.defaults`:
```
# HTTPS OTA: trust standard CAs (incl. GitHub) via the bundled cert store
CONFIG_MBEDTLS_CERTIFICATE_BUNDLE=y
CONFIG_MBEDTLS_CERTIFICATE_BUNDLE_DEFAULT_CMN=y
# OTA rollback: auto-revert if a new image never confirms a healthy boot
CONFIG_BOOTLOADER_APP_ROLLBACK_ENABLE=y
# Optimize for size to keep the image within the 1600K OTA slot
CONFIG_COMPILER_OPTIMIZATION_SIZE=y
```

- [ ] **Step 2: Add OTA options to `main/Kconfig.projbuild`**

Inside the existing `menu "Example Configuration"` … `endmenu` block (before `endmenu`), add:
```
    config OTA_POLL_INTERVAL_SEC
        int "OTA poll interval (seconds)"
        default 3600
        help
            How often the device checks GitHub Releases for a newer firmware.

    config OTA_GITHUB_BASE_URL
        string "GitHub repo base URL for OTA"
        default "https://github.com/larsakeekstrand/ESP32-homekit-garage-opener"
        help
            Base URL of the GitHub repo. The updater fetches
            <base>/releases/latest/download/version.txt and .../garage.bin
```

- [ ] **Step 3: Reconfigure + build clean**

```bash
. ~/esp/esp-idf/export.sh && cd ~/source/ESP32-homekit-garage-opener
rm -rf build && idf.py reconfigure 2>&1 | tail -5 && idf.py build 2>&1 | tail -20
```
Expected: `Project build complete.`, zero errors. Confirm the new Kconfig symbols resolve (no "unknown symbol" warnings). Note the app binary size line; with `-Os` it should be comfortably below 1600K (1638400 bytes).

- [ ] **Step 4: Sanity-check the size headroom**

```bash
SIZE=$(stat -f%z build/garage.bin 2>/dev/null || stat -c%s build/garage.bin); echo "garage.bin = $SIZE bytes (limit 1638400)"; [ "$SIZE" -le 1638400 ] && echo "FITS" || echo "OVERFLOW"
```
Expected: `FITS`. If `OVERFLOW`, STOP and report — the cert bundle (~tens of KB) outweighed the `-Os` savings and we must revisit (e.g. partition resize), which is out of this task's scope.

- [ ] **Step 5: Commit**

```bash
git add sdkconfig.defaults main/Kconfig.projbuild
git commit -m "build: enable cert bundle, OTA rollback, size opt; add OTA Kconfig

Co-Authored-By: Claude Opus 4.8 (1M context) <noreply@anthropic.com>"
```

---

### Task 3: The `ota_update` module (poller + version compare + HTTPS OTA)

Create the self-updating OTA module. Build it but don't wire it in yet (Task 4 does that), so this task's deliverable is a clean-compiling module with a host-verified version comparator.

**Files:**
- Create: `main/ota_update.h`, `main/ota_update.c`
- Modify: `main/CMakeLists.txt` (add `ota_update.c` to SRCS + `REQUIRES`)

**Interfaces:**
- Consumes: `CONFIG_OTA_POLL_INTERVAL_SEC`, `CONFIG_OTA_GITHUB_BASE_URL`, `FW_VERSION` (from Tasks 1–2).
- Produces (in `ota_update.h`):
  - `void ota_update_start(void);` — spawn the updater task.
  - `void ota_update_mark_valid(void);` — confirm the running image (cancel pending rollback).

- [ ] **Step 1: Create `main/ota_update.h`**

```c
//
// ota_update.h — self-polling GitHub-release OTA updater.
//
#pragma once

/* Spawn the background task that periodically checks GitHub Releases and
 * applies a newer firmware via HTTPS OTA. */
void ota_update_start(void);

/* Confirm the currently-running image after a healthy boot, cancelling any
 * pending rollback. Safe to call when rollback is not pending (no-op). */
void ota_update_mark_valid(void);
```

- [ ] **Step 2: Create `main/ota_update.c`**

```c
//
// ota_update.c — periodically poll GitHub Releases and OTA-update if newer.
//
#include <string.h>
#include <stdlib.h>
#include <freertos/FreeRTOS.h>
#include <freertos/task.h>
#include <esp_log.h>
#include <esp_http_client.h>
#include <esp_https_ota.h>
#include <esp_crt_bundle.h>
#include <esp_ota_ops.h>
#include <esp_system.h>

#include "ota_update.h"

static const char *TAG = "OTA";

#define OTA_BASE_URL      CONFIG_OTA_GITHUB_BASE_URL
#define VERSION_URL       OTA_BASE_URL "/releases/latest/download/version.txt"
#define FIRMWARE_URL      OTA_BASE_URL "/releases/latest/download/garage.bin"
#define POLL_INTERVAL_MS  (CONFIG_OTA_POLL_INTERVAL_SEC * 1000)
#define FIRST_CHECK_DELAY_MS 60000   /* let Wi-Fi/HAP settle and mark-valid run first */

/* Parse up to major.minor.patch from a version string. A non-numeric/missing
 * component (e.g. the "-dev" suffix) parses as 0. */
static void parse_ver(const char *s, int out[3]) {
    out[0] = out[1] = out[2] = 0;
    sscanf(s, "%d.%d.%d", &out[0], &out[1], &out[2]);
}

/* Return >0 if a is newer than b, <0 if older, 0 if equal. */
int ota_semver_cmp(const char *a, const char *b) {
    int va[3], vb[3];
    parse_ver(a, va);
    parse_ver(b, vb);
    for (int i = 0; i < 3; i++) {
        if (va[i] != vb[i]) return (va[i] > vb[i]) ? 1 : -1;
    }
    return 0;
}

/* Fetch the latest release's version.txt into buf (NUL-terminated, trimmed).
 * Returns ESP_OK on success. */
static esp_err_t fetch_latest_version(char *buf, size_t buf_len) {
    esp_http_client_config_t config = {
        .url = VERSION_URL,
        .crt_bundle_attach = esp_crt_bundle_attach,
        .timeout_ms = 15000,
    };
    esp_http_client_handle_t client = esp_http_client_init(&config);
    if (!client) return ESP_FAIL;

    esp_err_t err = esp_http_client_open(client, 0);
    if (err != ESP_OK) {
        ESP_LOGE(TAG, "Failed to open %s: %s", VERSION_URL, esp_err_to_name(err));
        esp_http_client_cleanup(client);
        return err;
    }
    esp_http_client_fetch_headers(client);
    int read = esp_http_client_read_response(client, buf, buf_len - 1);
    esp_http_client_close(client);
    esp_http_client_cleanup(client);
    if (read <= 0) return ESP_FAIL;

    buf[read] = '\0';
    /* trim trailing whitespace/newline */
    while (read > 0 && (buf[read - 1] == '\n' || buf[read - 1] == '\r' || buf[read - 1] == ' ')) {
        buf[--read] = '\0';
    }
    return ESP_OK;
}

/* Download and apply the latest firmware; reboots on success. */
static void do_ota(void) {
    ESP_LOGI(TAG, "Starting OTA from %s", FIRMWARE_URL);
    esp_http_client_config_t http_config = {
        .url = FIRMWARE_URL,
        .crt_bundle_attach = esp_crt_bundle_attach,
        .timeout_ms = 30000,
        .keep_alive_enable = true,
    };
    esp_https_ota_config_t ota_config = {
        .http_config = &http_config,
    };
    esp_err_t err = esp_https_ota(&ota_config);
    if (err == ESP_OK) {
        ESP_LOGI(TAG, "OTA successful; rebooting into new firmware");
        esp_restart();
    } else {
        ESP_LOGE(TAG, "OTA failed: %s", esp_err_to_name(err));
    }
}

static void ota_task(void *arg) {
    vTaskDelay(FIRST_CHECK_DELAY_MS / portTICK_PERIOD_MS);
    while (1) {
        char remote[32];
        if (fetch_latest_version(remote, sizeof(remote)) == ESP_OK) {
            if (ota_semver_cmp(remote, FW_VERSION) > 0) {
                ESP_LOGI(TAG, "Update available: running %s, latest %s", FW_VERSION, remote);
                do_ota();   /* reboots on success; falls through to retry on failure */
            } else {
                ESP_LOGI(TAG, "Up to date (running %s, latest %s)", FW_VERSION, remote);
            }
        } else {
            ESP_LOGW(TAG, "Version check failed; will retry");
        }
        vTaskDelay(POLL_INTERVAL_MS / portTICK_PERIOD_MS);
    }
}

void ota_update_start(void) {
    xTaskCreate(ota_task, "ota_update", 8 * 1024, NULL, 2, NULL);
}

void ota_update_mark_valid(void) {
    const esp_partition_t *running = esp_ota_get_running_partition();
    esp_ota_img_states_t state;
    if (esp_ota_get_state_partition(running, &state) == ESP_OK &&
        state == ESP_OTA_IMG_PENDING_VERIFY) {
        ESP_LOGI(TAG, "Marking running image valid (cancelling rollback)");
        esp_ota_mark_app_valid_cancel_rollback();
    }
}
```

- [ ] **Step 3: Register the source + dependencies in `main/CMakeLists.txt`**

Update the `idf_component_register` call to add `ota_update.c` and the OTA-related `REQUIRES`:
```cmake
idf_component_register(SRCS "app_main.c" "hap_garage.c" "dht_sensor.c" "door_control.c" "ota_update.c"
                       INCLUDE_DIRS "."
                       REQUIRES esp_https_ota esp_http_client app_update esp-tls mbedtls)
```
(Leave the `FW_VERSION` and `-Werror` lines from Task 1 unchanged.)

- [ ] **Step 4: Host-verify the version comparator (throwaway, not committed)**

```bash
cat > /tmp/semver_check.c <<'EOF'
#include <stdio.h>
#include <assert.h>
static void parse_ver(const char *s, int out[3]){out[0]=out[1]=out[2]=0;sscanf(s,"%d.%d.%d",&out[0],&out[1],&out[2]);}
int ota_semver_cmp(const char *a,const char *b){int va[3],vb[3];parse_ver(a,va);parse_ver(b,vb);for(int i=0;i<3;i++){if(va[i]!=vb[i])return va[i]>vb[i]?1:-1;}return 0;}
int main(void){
  assert(ota_semver_cmp("1.1.0","1.0.0")>0);
  assert(ota_semver_cmp("1.10.0","1.9.0")>0);   /* numeric, not lexical */
  assert(ota_semver_cmp("1.0.0","1.0.0")==0);
  assert(ota_semver_cmp("0.0.0-dev","1.0.0")<0);/* dev is oldest */
  assert(ota_semver_cmp("2.0.0","1.9.9")>0);
  assert(ota_semver_cmp("1.0.1","1.0.0")>0);
  printf("semver OK\n"); return 0;
}
EOF
cc /tmp/semver_check.c -o /tmp/semver_check && /tmp/semver_check && rm -f /tmp/semver_check /tmp/semver_check.c
```
Expected: `semver OK`. (This mirrors the exact `parse_ver`/`ota_semver_cmp` logic from `ota_update.c`. It is not added to the repo.)

- [ ] **Step 5: Build clean**

```bash
. ~/esp/esp-idf/export.sh && cd ~/source/ESP32-homekit-garage-opener && idf.py build 2>&1 | tail -20
```
Expected: `Project build complete.`, zero errors. (`ota_update.c` compiles with `-Werror`; `esp_crt_bundle.h`/`esp_https_ota.h` resolve via the `REQUIRES`.) Confirm `garage.bin` still fits (re-run the Task 2 Step 4 size check).

- [ ] **Step 6: Commit**

```bash
git add main/ota_update.c main/ota_update.h main/CMakeLists.txt
git commit -m "feat: add self-polling GitHub-release OTA updater module

Co-Authored-By: Claude Opus 4.8 (1M context) <noreply@anthropic.com>"
```

---

### Task 4: Wire OTA into `app_main`; remove `hap_fw_upgrade`

Start the updater, confirm healthy boots, and drop the obsolete HomeKit upgrade service.

**Files:**
- Modify: `main/app_main.c`
- Modify: `main/hap_garage.c`

**Interfaces:**
- Consumes: `ota_update_start()`, `ota_update_mark_valid()` (Task 3).
- Produces: nothing new.

- [ ] **Step 1: Wire the updater into `main/app_main.c`**

Add the include and update the task body + `app_main`:
```c
#include "ota_update.h"
```
In `garage_thread_entry`, call `ota_update_mark_valid()` once the device is healthy (after Wi-Fi/HAP are up, before the event loop):
```c
static void garage_thread_entry(void *p) {
  hap_garage_init();
  door_control_init();
  hap_garage_start();
  hap_garage_start_wifi();   // blocking; returns once Wi-Fi/HAP are up
  ota_update_mark_valid();   // healthy boot confirmed → cancel any pending rollback
  door_control_run_loop();   // never returns
}
```
In `app_main`, spawn the updater task alongside the others:
```c
void app_main(void) {
  xTaskCreate(garage_thread_entry, "hap_garage", GARAGE_TASK_STACKSIZE, NULL, 1, NULL);
  dht_sensor_start();
  ota_update_start();
}
```

- [ ] **Step 2: Remove `hap_fw_upgrade` from `main/hap_garage.c`**

Delete all of these:
- the include: `#include <hap_fw_upgrade.h>`
- the global: `char server_cert[] = {};` (and its comment)
- in `hap_garage_init`, the FW-upgrade service block — the `hap_fw_upgrade_config_t ota_config = { .server_cert_pem = server_cert };`, the `service = hap_serv_fw_upgrade_create(&ota_config);`, and the matching `hap_acc_add_serv(accessory, service);` for that service. (Keep the Garage Door Opener, Temperature, and Humidity service additions intact.)

- [ ] **Step 3: Build clean**

```bash
. ~/esp/esp-idf/export.sh && cd ~/source/ESP32-homekit-garage-opener && idf.py build 2>&1 | tail -20
```
Expected: `Project build complete.`, zero errors, no unused-variable/`-Werror` failures from the removed code. Confirm `garage.bin` still fits (Task 2 Step 4 check).

- [ ] **Step 4: Commit**

```bash
git add main/app_main.c main/hap_garage.c
git commit -m "feat: start OTA updater + mark-valid; remove hap_fw_upgrade service

Co-Authored-By: Claude Opus 4.8 (1M context) <noreply@anthropic.com>"
```

---

### Task 5: CI build workflow

Build the firmware on every push to `main` and every PR to `main`.

**Files:**
- Create: `.github/workflows/build.yml`

**Interfaces:** none (CI config).

- [ ] **Step 1: Create `.github/workflows/build.yml`**

```yaml
name: Build

on:
  push:
    branches: [main]
  pull_request:
    branches: [main]

jobs:
  build:
    runs-on: ubuntu-latest
    steps:
      - name: Checkout
        uses: actions/checkout@v4

      - name: Clone pinned esp-homekit-sdk
        run: |
          git clone https://github.com/espressif/esp-homekit-sdk.git "$GITHUB_WORKSPACE/esp-homekit-sdk"
          git -C "$GITHUB_WORKSPACE/esp-homekit-sdk" checkout 676fabac4a4a05184be020611cb069faa0016411
          git -C "$GITHUB_WORKSPACE/esp-homekit-sdk" submodule update --init --recursive

      - name: Build firmware
        uses: espressif/esp-idf-ci-action@v1
        with:
          esp_idf_version: v5.5.2
          target: esp32
          command: |
            export HOMEKIT_PATH="$GITHUB_WORKSPACE/esp-homekit-sdk"
            idf.py set-target esp32 build

      - name: Check image fits the OTA partition
        run: |
          SIZE=$(stat -c%s build/garage.bin)
          LIMIT=$((1600 * 1024))
          echo "garage.bin = $SIZE bytes (limit $LIMIT)"
          test "$SIZE" -le "$LIMIT"

      - name: Upload firmware artifact
        uses: actions/upload-artifact@v4
        with:
          name: garage-bin
          path: build/garage.bin
```

- [ ] **Step 2: Validate the YAML**

```bash
cd ~/source/ESP32-homekit-garage-opener
python3 -c "import yaml,sys; yaml.safe_load(open('.github/workflows/build.yml')); print('YAML OK')"
command -v actionlint >/dev/null && actionlint .github/workflows/build.yml || echo "(actionlint not installed; skipped)"
```
Expected: `YAML OK` (and actionlint clean if present). The build commands mirror the locally-proven `idf.py set-target esp32 build`; warnings-as-errors comes from the `-Werror` added in Task 1. First-push run on GitHub is the real proof.

- [ ] **Step 3: Commit**

```bash
git add .github/workflows/build.yml
git commit -m "ci: build firmware on push and PR to main

Co-Authored-By: Claude Opus 4.8 (1M context) <noreply@anthropic.com>"
```

---

### Task 6: Release workflow

Manually-dispatched workflow that builds a versioned image and publishes a GitHub Release.

**Files:**
- Create: `.github/workflows/release.yml`

**Interfaces:** none (CI config).

- [ ] **Step 1: Create `.github/workflows/release.yml`**

```yaml
name: Release

on:
  workflow_dispatch:
    inputs:
      version:
        description: "Release version (e.g. 1.1.0, no leading v)"
        required: true
        type: string

permissions:
  contents: write

jobs:
  release:
    runs-on: ubuntu-latest
    steps:
      - name: Checkout
        uses: actions/checkout@v4

      - name: Clone pinned esp-homekit-sdk
        run: |
          git clone https://github.com/espressif/esp-homekit-sdk.git "$GITHUB_WORKSPACE/esp-homekit-sdk"
          git -C "$GITHUB_WORKSPACE/esp-homekit-sdk" checkout 676fabac4a4a05184be020611cb069faa0016411
          git -C "$GITHUB_WORKSPACE/esp-homekit-sdk" submodule update --init --recursive

      - name: Build firmware (versioned)
        uses: espressif/esp-idf-ci-action@v1
        with:
          esp_idf_version: v5.5.2
          target: esp32
          command: |
            export HOMEKIT_PATH="$GITHUB_WORKSPACE/esp-homekit-sdk"
            idf.py -DFW_VERSION="${{ inputs.version }}" set-target esp32 build

      - name: Check image fits the OTA partition
        run: |
          SIZE=$(stat -c%s build/garage.bin)
          LIMIT=$((1600 * 1024))
          echo "garage.bin = $SIZE bytes (limit $LIMIT)"
          test "$SIZE" -le "$LIMIT"

      - name: Write version.txt
        run: printf '%s' "${{ inputs.version }}" > version.txt

      - name: Create GitHub Release
        uses: softprops/action-gh-release@v2
        with:
          tag_name: v${{ inputs.version }}
          name: v${{ inputs.version }}
          generate_release_notes: true
          files: |
            build/garage.bin
            version.txt
```

- [ ] **Step 2: Validate the YAML + the versioned build locally**

```bash
cd ~/source/ESP32-homekit-garage-opener
python3 -c "import yaml; yaml.safe_load(open('.github/workflows/release.yml')); print('YAML OK')"
command -v actionlint >/dev/null && actionlint .github/workflows/release.yml || echo "(actionlint not installed; skipped)"
. ~/esp/esp-idf/export.sh && idf.py -DFW_VERSION="1.2.3" reconfigure 2>&1 | grep "Building firmware version"
idf.py -DFW_VERSION=0.0.0-dev reconfigure >/dev/null   # reset
```
Expected: `YAML OK` and `Building firmware version: 1.2.3` (confirms the release build's version injection works). GitHub-side run is the real proof (the user dispatches it once).

- [ ] **Step 3: Commit**

```bash
git add .github/workflows/release.yml
git commit -m "ci: add manual release workflow publishing garage.bin + version.txt

Co-Authored-By: Claude Opus 4.8 (1M context) <noreply@anthropic.com>"
```

---

### Task 7: Documentation

Document the CI, the release process, and the self-updating OTA behavior.

**Files:**
- Modify: `README.md`
- Modify: `CLAUDE.md`

**Interfaces:** none.

- [ ] **Step 1: Update `README.md`**

Add a "Continuous Integration & Releases" section covering:
- CI builds every push/PR to `main` (link/badge optional: `![Build](https://github.com/larsakeekstrand/ESP32-homekit-garage-opener/actions/workflows/build.yml/badge.svg)`).
- Cutting a release: in the GitHub **Actions** tab, run the **Release** workflow (`workflow_dispatch`) and enter the version (e.g. `1.1.0`). It tags `v1.1.0` and publishes a Release with `garage.bin` + `version.txt`.
- OTA: the device checks `releases/latest` hourly and auto-updates to a newer version; a bad image is rolled back automatically by the bootloader. Interval/repo configurable via `idf.py menuconfig` (Example Configuration → OTA options).

- [ ] **Step 2: Update `CLAUDE.md`**

- Architecture: add `ota_update.{c,h}` to the module table (self-polling GitHub-release OTA: hourly version check, `esp_https_ota` with cert bundle, rollback) and note `hap_fw_upgrade` was removed (HomeKit no longer carries an upgrade service).
- Note the `app_main` startup now also calls `ota_update_start()` and `ota_update_mark_valid()` (after Wi-Fi/HAP up).
- Configuration: mention `FW_VERSION` build injection (default `0.0.0-dev`; releases set it), the new `sdkconfig.defaults` entries (cert bundle, rollback, `-Os`), and the OTA Kconfig options.
- Commands/CI: mention the two workflows and that the build uses `-Werror` for app sources.

- [ ] **Step 3: Build remains green + commit**

```bash
. ~/esp/esp-idf/export.sh && cd ~/source/ESP32-homekit-garage-opener && idf.py build 2>&1 | tail -5
git add README.md CLAUDE.md
git commit -m "docs: document CI, releases, and self-updating OTA

Co-Authored-By: Claude Opus 4.8 (1M context) <noreply@anthropic.com>"
```

- [ ] **Step 4: On-device end-to-end OTA test (user runs, after merge + first release)**

This is the real proof of the OTA path and can only be done by the user with hardware:
1. Flash a build at a low version: `idf.py -DFW_VERSION=1.0.0 flash monitor`.
2. Dispatch the Release workflow with a higher version (e.g. `1.0.1`); wait for the Release to publish.
3. Watch the monitor: within the poll interval the `OTA` task logs "Update available… running 1.0.0, latest 1.0.1", downloads, and reboots into 1.0.1 (verify via `fw_rev` in the Home app or the boot log).
4. (Optional) Confirm rollback by publishing a deliberately-broken image and verifying the bootloader reverts.

---

## Self-Review

**Spec coverage:**
- CI build on push/PR + warnings-as-errors + partition-fit + artifact → Task 5 (+ `-Werror` in Task 1). ✓
- Release `workflow_dispatch` w/ version → tag + Release w/ `garage.bin` + `version.txt` → Task 6. ✓
- Build-time `FW_VERSION` → `fw_rev` + OTA baseline → Task 1. ✓
- `ota_update` module: hourly poll, `version.txt` fetch, semver compare, `esp_https_ota` + cert bundle, reboot → Task 3. ✓
- Rollback enable + mark-valid after healthy boot → Task 2 (config) + Task 3 (`ota_update_mark_valid`) + Task 4 (call site). ✓
- Remove `hap_fw_upgrade` + `server_cert` → Task 4. ✓
- `sdkconfig.defaults` cert bundle / rollback / `-Os`; Kconfig interval + base URL → Task 2. ✓
- Docs → Task 7. ✓
- Verification (build, YAML, on-device) → per-task + Task 7 Step 4. ✓
- Out of scope (tests, signed OTA, multi-target, CI-push) → not present. ✓

**Placeholder scan:** No TBD/TODO. All code blocks are complete. The host semver check is concrete and runnable.

**Type consistency:** `ota_update_start(void)` / `ota_update_mark_valid(void)` declared in `ota_update.h` (Task 3) and called in `app_main.c` (Task 4) — match. `ota_semver_cmp(const char*, const char*)` internal to Task 3 and mirrored exactly in the host check. `FW_VERSION` produced in Task 1, consumed in Tasks 3–4. Kconfig symbols `CONFIG_OTA_POLL_INTERVAL_SEC`/`CONFIG_OTA_GITHUB_BASE_URL` produced in Task 2, consumed in Task 3. Asset names `garage.bin`/`version.txt` consistent across Tasks 3/5/6. SDK pin `676fabac…` consistent across Tasks 5/6 and Global Constraints.

**Note on CI env (`HOMEKIT_PATH` inside the container):** the `esp-idf-ci-action` runs the `command` in the IDF container with the workspace mounted; `$GITHUB_WORKSPACE/esp-homekit-sdk` is exported inside that command. If the first CI run shows the SDK isn't found at that path, the fix is to adjust the exported path to the in-container workspace mount (reported by the action's log) — flagged here so the implementer checks the first run rather than assuming.

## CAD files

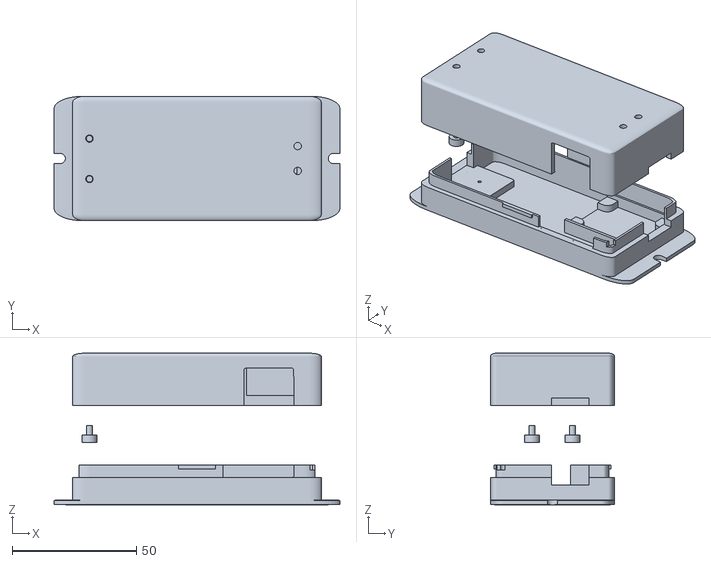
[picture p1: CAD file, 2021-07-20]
docs/GarageOpenerCompleteNotPrintable.stl
115.0 x 50.0 x 61.0

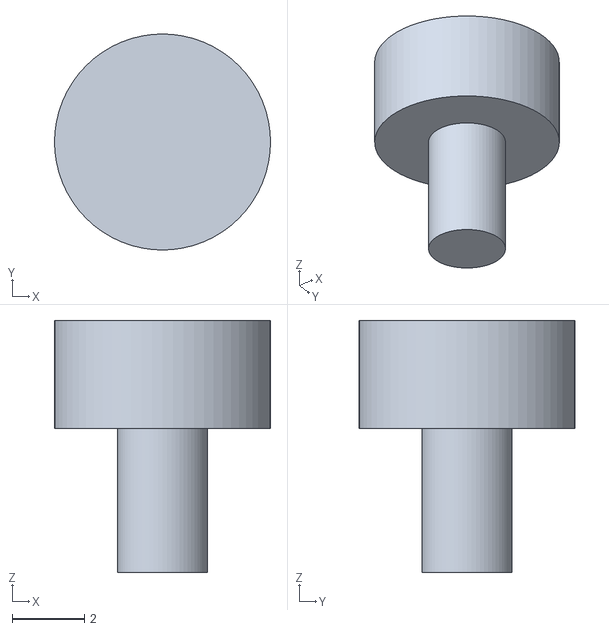
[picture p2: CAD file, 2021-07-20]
docs/GarageOpenerBottomButton.stl
6.00 x 6.00 x 7.00

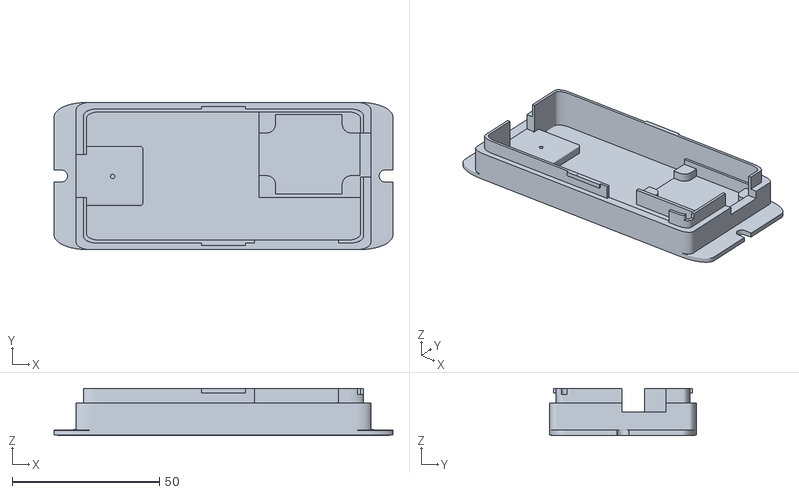
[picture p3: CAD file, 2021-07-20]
docs/GarageOpenerBottom.stl
115.0 x 50.0 x 16.0

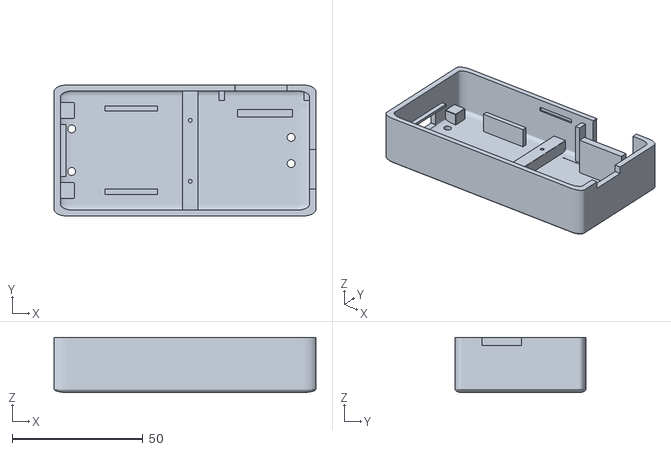
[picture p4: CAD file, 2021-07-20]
docs/GarageOpenerTop.stl
100.0 x 50.0 x 21.0

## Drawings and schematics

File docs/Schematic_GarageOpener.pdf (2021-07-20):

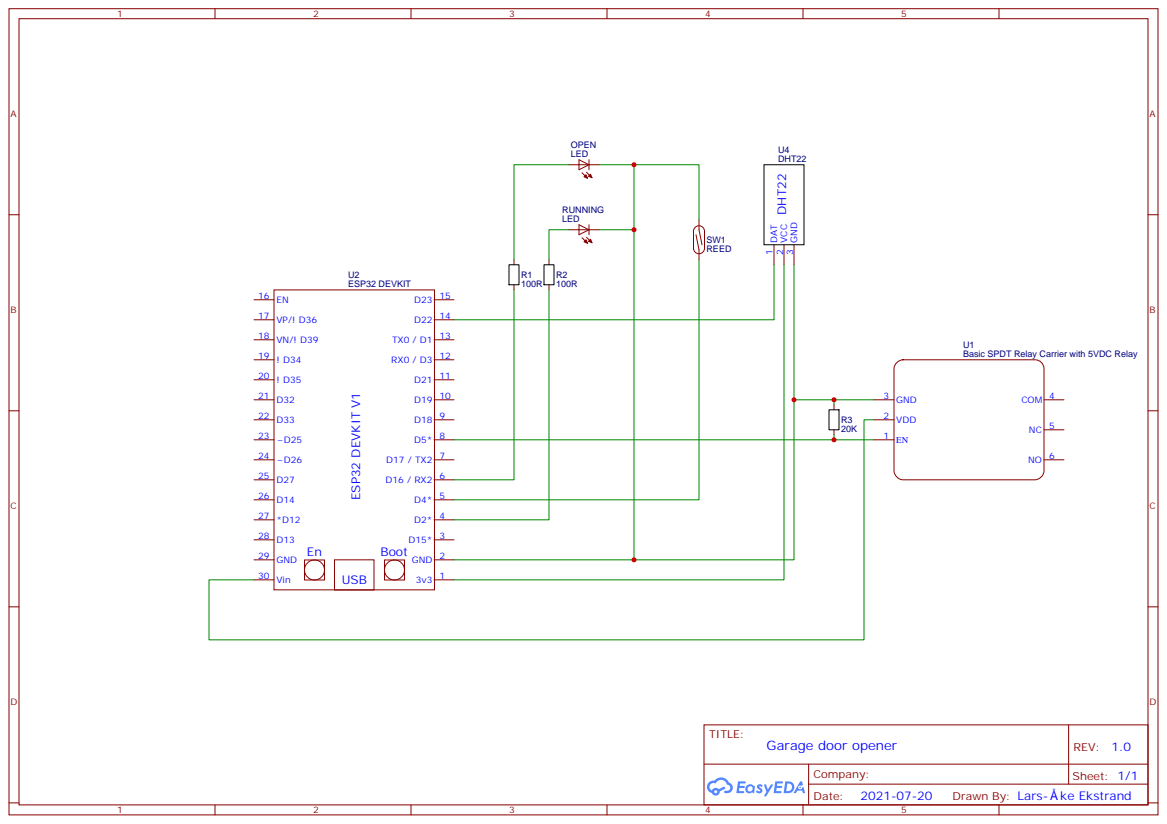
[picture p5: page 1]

Basic SPDT Relay Carrier with 5VDC Relay

Drawn By: Lars- ke Ekstrand

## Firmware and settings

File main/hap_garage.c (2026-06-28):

//
// hap_garage.c — HomeKit accessory and all HAP I/O.
//
#include <string.h>
#include <freertos/FreeRTOS.h>
#include <esp_log.h>
#include <esp_event.h>
#include <esp_wifi.h>

#include <hap.h>
#include <hap_apple_servs.h>
#include <hap_apple_chars.h>
#include <iot_button.h>
#include <app_wifi.h>
#include <app_hap_setup_payload.h>

#include "hap_garage.h"
#include "door_control.h"
#include "dht_sensor.h"
#include "board.h"

static const char *TAG = "HAP Garage";

static hap_acc_t *accessory;

/* Reset button timeouts. */
#define RESET_NETWORK_BUTTON_TIMEOUT    3
#define RESET_TO_FACTORY_BUTTON_TIMEOUT 10

//
// Convert door state to string
//
static char *door_state_to_string(uint8_t state) {
  switch(state) {
    case HOMEKIT_CHARACTERISTIC_CURRENT_DOOR_STATE_OPEN:    return "open";
    case HOMEKIT_CHARACTERISTIC_CURRENT_DOOR_STATE_CLOSED:  return "closed";
    case HOMEKIT_CHARACTERISTIC_CURRENT_DOOR_STATE_OPENING: return "opening";
    case HOMEKIT_CHARACTERISTIC_CURRENT_DOOR_STATE_CLOSING: return "closing";
    case HOMEKIT_CHARACTERISTIC_CURRENT_DOOR_STATE_STOPPED: return "stopped";
    default:                                                 return "unknown";
  }
}

//
// Send update of current door state
//
void hap_garage_send_current_door_state(uint8_t state) {
  hap_val_t door_value = { .u = state };
  hap_serv_t *service = hap_acc_get_serv_by_uuid(accessory, HAP_SERV_UUID_GARAGE_DOOR_OPENER);
  hap_char_t *handle  = hap_serv_get_char_by_uuid(service, HAP_CHAR_UUID_CURRENT_DOOR_STATE);
  ESP_LOGI(TAG, "Sending current doorstate [%s]", door_state_to_string(state));
  hap_char_update_val(handle, &door_value);
}

//
// Send update of target door state
//
void hap_garage_send_target_door_state(uint8_t state) {
  hap_val_t door_value = { .u = state };
  hap_serv_t *service = hap_acc_get_serv_by_uuid(accessory, HAP_SERV_UUID_GARAGE_DOOR_OPENER);
  hap_char_t *handle  = hap_serv_get_char_by_uuid(service, HAP_CHAR_UUID_TARGET_DOOR_STATE);
  ESP_LOGI(TAG, "Sending target doorstate [%s]", door_state_to_string(state));
  hap_char_update_val(handle, &door_value);
}

//
// Send update of current temperature
//
void hap_garage_send_current_temperature(float temperature) {
  hap_val_t v = { .f = temperature };
  hap_serv_t *s = hap_acc_get_serv_by_uuid(accessory, HAP_SERV_UUID_TEMPERATURE_SENSOR);
  hap_char_t *h = hap_serv_get_char_by_uuid(s, HAP_CHAR_UUID_CURRENT_TEMPERATURE);
  ESP_LOGI(TAG, "Sending current temperature [%f]", temperature);
  hap_char_update_val(h, &v);
}

//
// Send update of current humidity
//
void hap_garage_send_current_humidity(float humidity) {
  hap_val_t v = { .f = humidity };
  hap_serv_t *s = hap_acc_get_serv_by_uuid(accessory, HAP_SERV_UUID_HUMIDITY_SENSOR);
  hap_char_t *h = hap_serv_get_char_by_uuid(s, HAP_CHAR_UUID_CURRENT_RELATIVE_HUMIDITY);
  ESP_LOGI(TAG, "Sending current humidity [%f]", humidity);
  hap_char_update_val(h, &v);
}

//
// Mandatory identify routine for the accessory.
//
// TODO: Maybe add a LED blink later?
//
static int garage_identify(hap_acc_t *ha)
{
    ESP_LOGI(TAG, "Accessory identified");
    return HAP_SUCCESS;
}

//
// An optional HomeKit Event handler which can be used to track HomeKit
// specific events.
//
static void garage_hap_event_handler(void* arg, esp_event_base_t event_base, int32_t event, void *data)
{
    switch(event) {
        case HAP_EVENT_PAIRING_STARTED :
            ESP_LOGI(TAG, "Pairing Started");
            break;
        case HAP_EVENT_PAIRING_ABORTED :
            ESP_LOGI(TAG, "Pairing Aborted");
            break;
        case HAP_EVENT_CTRL_PAIRED :
            ESP_LOGI(TAG, "Controller %s Paired. Controller count: %d",
                        (char *)data, hap_get_paired_controller_count());
            break;
        case HAP_EVENT_CTRL_UNPAIRED :
            ESP_LOGI(TAG, "Controller %s Removed. Controller count: %d",
                        (char *)data, hap_get_paired_controller_count());
            break;
        case HAP_EVENT_CTRL_CONNECTED :
            ESP_LOGI(TAG, "Controller %s Connected", (char *)data);
            break;
        case HAP_EVENT_CTRL_DISCONNECTED :
            ESP_LOGI(TAG, "Controller %s Disconnected", (char *)data);
            break;
        case HAP_EVENT_ACC_REBOOTING : {
            char *reason = (char *)data;
            ESP_LOGI(TAG, "Accessory Rebooting (Reason: %s)",  reason ? reason : "null");
            break;
        }
        default:
            /* Silently ignore unknown events */
            break;
    }
}

/**
 * @brief The network reset button callback handler.
 * Useful for testing the Wi-Fi re-configuration feature of WAC2
 */
static void reset_network_handler(void* arg)
{
    ESP_LOGI(TAG, "Reset network");
    hap_reset_network();
}

/**
 * @brief The factory reset button callback handler.
 */
static void reset_to_factory_handler(void* arg)
{
    ESP_LOGI(TAG, "Reset to factory");
    hap_reset_to_factory();
}

/**
 * The Reset button  GPIO initialisation function.
 * Same button will be used for resetting Wi-Fi network as well as for reset to factory based on
 * the time for which the button is pressed.
 */
static void reset_key_init(uint32_t key_gpio_pin)
{
    button_handle_t handle = iot_button_create(key_gpio_pin, BUTTON_ACTIVE_LOW);
    iot_button_add_on_release_cb(handle, RESET_NETWORK_BUTTON_TIMEOUT, reset_network_handler, NULL);
    iot_button_add_on_press_cb(handle, RESET_TO_FACTORY_BUTTON_TIMEOUT, reset_to_factory_handler, NULL);
}
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

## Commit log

2021-07-20 Added support for DHT temp and humidity sensor
2021-07-20 Added schematics
2021-07-20 Added stl files
    [GarageOpenerBottom.stl, GarageOpenerTop.stl]
2021-07-20 Updated readme with stl files
2021-07-20 Added STL files for buttons
    [GarageOpenerBottomButton.stl, GarageOpenerCompleteNotPrintable.stl]
2021-07-20 Added more stl files
2026-06-28 Add design spec for ESP-IDF v5.5.2 modernization
    Approved design: migrate build to v5.5.2 (CMake-only, Component Manager
    for the DHT driver, re-cloned esp-homekit-sdk peer), split app_main.c
    into focused modules, and fix known bugs (debounce, no-op dht_read,
    swapped DHT log). No new features.
2026-06-28 Add implementation plan for ESP-IDF v5.5.2 modernization
    Seven build-driven tasks: build/dep migration + API fixes, then extract
    board.h, hap_garage, dht_sensor, door_control modules, thin app_main, and
    update docs + on-device smoke test. No unit tests (hardware-bound firmware,
    no harness); each task gated on a clean idf.py build.
2026-06-28 Fix workspace-layout assumption in modernization plan
    Repo is at ~/source/ESP32-homekit-garage-opener (sibling of ~/esp/), not
    nested in esp/source as the old README claimed. Correct the CMake fallback
    to ../../esp/esp-homekit-sdk and all build command paths.
2026-06-28 build: migrate to ESP-IDF v5.5.2 (CMake-only, Component Manager DHT)
    Remove legacy GNU-make build; re-point EXTRA_COMPONENT_DIRS at re-cloned
    esp-homekit-sdk peer; add idf_component.yml for the DHT driver. Mechanical
    API fixes: xQueueHandle->QueueHandle_t, portTICK_RATE_MS->portTICK_PERIOD_MS,
    zero-init gpio_config_t, int->int32_t in esp_event_handler_t callback.
    Behavior unchanged. esp-homekit-sdk @ 676faba.
2026-06-28 refactor: extract board.h with GPIO pin map
2026-06-28 refactor: extract door_control; add reed debounce; consolidate state machine
    Move door state machine, relay, ISR/queue, failsafe timer, and event loop
    into door_control.{c,h}. Add ~50ms reed-sensor debounce and collapse the
    8-branch reconciliation into one explicit transition.
    [door_control.c]
2026-06-28 refactor: thin app_main.c to composition root; remove dead code
    - app_main.c: drop unused macros (GARAGE_TASK_PRIORITY, GARAGE_TASK_NAME,
    esp_log.h include); inline literal priority and task name per brief.
    - hap_garage.c: make door_state_to_string static (internal only).
    - hap_garage.h: remove door_state_to_string from public interface.
    - hap_garage.c garage_read: remove const hap_val_t *cur_val; copy
    obstruction value into hap_val_t obs_val to fix
    -Wincompatible-pointer-types-discards-qualifiers warning.
    Build: Project build complete. Zero errors, zero warnings from our sources.
    App partition: 0x187920 bytes / 0x190000 (98% used, 2% free).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
    [hap_garage.c, hap_garage.h]
2026-06-28 fix: tighten init ordering and read-cb status (final review)
    - create reed-sensor event queue before installing the GPIO ISR (NULL-queue race)
    - split hap_start() into hap_garage_start(), invoked after door_control_init()
    - garage_read sets a default HAP_STATUS_SUCCESS for unhandled characteristics
    [door_control.c, hap_garage.c, hap_garage.h]
2026-06-28 Add implementation plan for CI/CD + self-updating OTA
    Seven tasks: FW_VERSION injection + -Werror, config (cert bundle/rollback/-Os
    + Kconfig), ota_update module (host-verified semver), wire-in + remove
    hap_fw_upgrade, CI build workflow, release workflow, docs. Build-driven gate
    per task; on-device OTA test by the user.
2026-06-28 docs: note Wi-Fi creds live in NVS across OTA; BLE re-provisioning
    Credentials persist in the nvs partition (untouched by OTA); release images
    are provisioning-mode. Document BLE provisioning (ESP BLE Provisioning app,
    PROV_xxxxxx + POP/QR) and the reset-button re-provision triggers.
2026-06-28 ci: pin third-party actions to commit SHAs (supply-chain hardening)
    Pin actions/checkout, actions/upload-artifact, espressif/esp-idf-ci-action,
    and softprops/action-gh-release to full commit SHAs (with # vX comments) so a
    moved tag can't alter CI. Bump deliberately via Dependabot.
2026-06-28 feat: Wi-Fi stability tuning for weak-signal installs
    Layer extra Wi-Fi tuning on top of app_wifi, entirely in-repo (not in the
    shared esp-homekit-sdk app_wifi.c, which CI clones fresh and would not ship):
    - Disable modem sleep (esp_wifi_set_ps(WIFI_PS_NONE)) so missed beacons on a
    weak link don't get the device aged out — the main fix for spurious drops on
    a mains-powered opener.
    - On first connect: max TX power (21 dBm) and switch the stored config to
    all-channel scan + connect-by-signal so reconnects pick the strongest BSSID.
    - Log the disconnect reason code + RSSI so weak-signal drops are diagnosable.
    Tuning calls warn on failure instead of aborting. Handlers are additive
    (esp_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
    [hap_garage.c]
2026-07-04 feat: log Wi-Fi RSSI to serial every 30s for signal diagnostics
    Adds a lightweight esp_timer that logs the current AP RSSI (dBm) plus a
    quality label and BSSID, so weak-signal installs can be diagnosed from the
    serial monitor without extra hardware or HomeKit changes. Timer is created
    once in the one-shot GOT_IP block (reconnect-safe) and reports "not
    connected" if the link is down.
2026-07-04 fix: correct reed sensor polarity so door open/closed isn't inverted
    The reed switch reads low when the door is closed and high when open on
    this install, but read_door_sensor() XOR-inverted the level, so HomeKit
    reported closed as open and vice versa. Drop the inversion so the pin maps
    straight onto DOOR_CLOSED (0) / DOOR_OPEN (1). All consumers read through
    this single accessor, so this corrects init, the run loop, the failsafe
    timer, and the HomeKit request handler at once.
2026-07-04 docs: add printable ESP32-WROOM-32U wiring diagram
    Self-contained HTML wiring reference for moving the firmware to a 38-pin
    WROOM-32U module: board pin map with the six used GPIOs highlighted, an
    authoritative connection table (from main/board.h), and strapping/antenna
    notes. Open in a browser and print (A4 portrait).
2026-07-04 docs: add power-distribution section to WROOM-32U wiring diagram
    Documents that peripherals are powered through the board (as on the old
    30-pin design per docs/Schematic_GarageOpener.pdf): USB 5V feeds the module,
    the 5V relay taps the 5V pin (old Vin), the DHT22 runs off 3V3, GND common.
    Adds a Vin->5V / 3v3->3V3 pin-equivalence note and corrects the relay/DHT
    notes to match the original schematic (R3 pull on relay EN; no separate DHT
    data pull-up).
2026-07-04 docs: add HomeKit board-migration guide
    Explains that a HomeKit pairing can't transfer between boards (device ID is
    derived from the MAC), and gives the remove-old + add-new procedure: flash and
    Wi-Fi-provision the new board, add it in the Home app with setup code
    111-22-333, then remove the old accessory. Includes the Boot-button reset table
    for a stuck pairing.
2026-07-04 docs: fix missing IO21 in WROOM-32U wiring diagram
    The right-hand pin column omitted IO21 (sits between RX0 and the second GND),
    making the column 18 pins instead of 19 and shifting IO5/IO16/IO4/IO0/IO2 up
    one position — which mislabeled the relay pin. Verified against the physical
    board: both columns now 19 pins.
2026-07-04 docs: add design spec for safety features + local status web page
    Auto-close timer, door-left-open Contact Sensor alert, absolute
    vacation/lockout switch, and an authenticated local status/config web
    page. Includes auto-close fault detection to prevent a stuck reed
    sensor from oscillating the door.
2026-07-04 feat(hap): add left-open contact sensor, lockout switch, and status-fault char
2026-07-04 feat(door): auto-close, left-open alert, and stuck-sensor fault detection
2026-07-05 docs: add design spec for LAN push-OTA (device endpoint + Rust CLI)
2026-07-05 fix(tools): surface device error body on resume/status failures
2026-07-05 feat(web): redesign the status page + fix charset mojibake
    Redesign the local web UI as a dark instrument-panel dashboard (door-state
    hero with live indicator, amber accent, monospace readouts, custom switches,
    responsive). Declare <meta charset=utf-8> and serve text/html; charset=utf-8
    so the degC / em-dash / middot characters render correctly instead of mojibake.
    No endpoint or behavior change; all element IDs and JS wiring preserved.
2026-07-05 docs: add design spec for runtime settings + device controls in web UI
2026-07-05 docs: add implementation plan for web UI settings + device controls
2026-07-05 feat(settings): add ota_poll_sec, door_move_sec, relay_pulse_ms tunables
2026-07-05 feat(door): read door-move timeout and relay pulse from settings
2026-07-05 feat(web): editable OTA poll / door-move / relay settings + check-now + reboot UI
    Adds Updates and Door-tuning cards, a Check-for-updates-now button, and a
    Reboot button to the status page. Also introduces a maintainable page source
    (tools/web/*.html) + regenerator (tools/gen_web_page.py) so the embedded HTML
    is edited as real HTML instead of escaped C strings.
2026-07-05 fix(web): prompt first OTA check after boot; 409 on paused check-now; page-level Save; docs
    Final-review fixes for v1.3.2:
    - ota_update: start the poll accumulator 'due' so the first version check runs
    ~10 s after boot (not a full interval later) — OTA is the self-heal path.
    Removed the now-dead POLL_INTERVAL_MS define.
    - /api/ota-check returns 409 while paused so the page surfaces the message
    instead of silently doing nothing.
    - Moved the settings Save button out of the Timers card to a page-level
    'Save all settings' so it clearly saves the Updates/Door-tuning fields too.
    - README: warn to edit only tools/web/*.html (the C strings are generated).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
